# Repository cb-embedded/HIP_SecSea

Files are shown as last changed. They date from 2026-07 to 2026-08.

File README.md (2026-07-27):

# HIP_SecSea
Hack In Provence badge for SecSea

## Changes from V1.1 (@chris_cannes)

This version is based on the V1.1 design by @chris_cannes. The following changes were made:

**Antenna area**
- Antenna placement and copper zones reworked to comply with CC1101 datasheet requirements.
- Replaced four independent copper cutout polygons with a proper keepout zone (larger, as required by the doc).

**Layer stackup**
- Added a dedicated Ground plane (inner layer).
- Added a dedicated 3.3V Power plane (inner layer).
- Main routing moved to Top and Bottom layers.

**Power distribution**
- The 3.3V distribution tree replaced by a solid 3.3V power plane.

**GND stitching**
- Stitching vias replaced by GND vias placed as close as possible to GND pads, connecting directly into the ground plane. This ensures a controlled, low-impedance GND return path.

## TODO (before production)

- [X] Rebuild copper planes and stitching vias: add back a proper grid of stitching vias (perimeter, around RF keepout zone, under CC1101) in addition to the pad-level GND vias.
- [X] **Replace C21 and C26 — 220pF X7R on RF path**: TI reference design specifies NP0/C0G for these positions. Replace with Murata [`GRM1555C1H221JA01D`](https://www.lcsc.com/product-detail/C71693.html) (C0G, 220pF, 50V, 0402, LCSC C71693). Current part [`0402B221K500NT`](https://www.lcsc.com/product-detail/C1530.html) (FH, LCSC C1530, X7R) deviates from reference design; do not second-guess NP0 in an RF path.
- [X] **Verify crystal load capacitors C17, C18 (27pF)**: X2 specifies 15pF load. CC1101 datasheet gives Cparasitic ≈ 2.5pF typical. Effective load = 27/2 + 2.5 = 16pF — 1pF above target, acceptable. Current 27pF value is correct; no change needed unless crystal frequency trim is required.

- [ ] Use tented vias;
- [X] On ne le fait plus (trop long) ~~TODO: Changer pour antenne 868MHz (Meilleure efficacité vs petite taille de PCB), (si simple à changer).~~
- [ ] Prod entre 5 et 10.

## Production Preview JLCPCB

See [JLCPCB Pictures in this folder](KiCad_src_V1_2/production_preview)

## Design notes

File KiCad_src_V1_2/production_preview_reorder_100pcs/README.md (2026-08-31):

# Production JLCPCB 100pcs

## Coût

Coût d'environs **14€ par Badge pour 100pcs** *(contre 65€ lors de la phase de prototypage)*

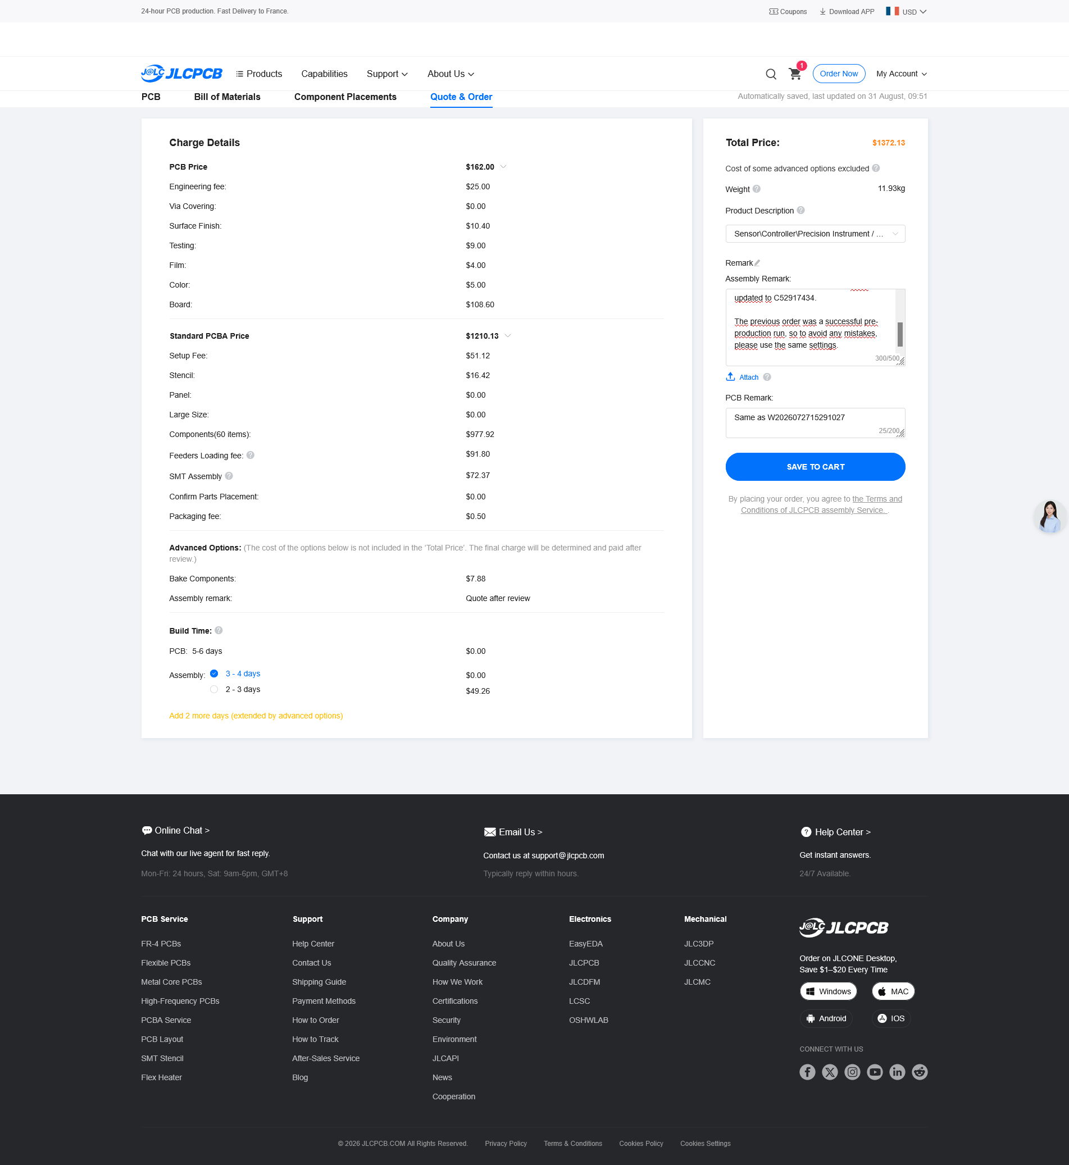
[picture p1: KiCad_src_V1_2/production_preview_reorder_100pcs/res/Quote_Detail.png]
Quote


## Remarques

- **Mise à jour mineure de la BOM:**
  - La référence des LEDs WS2812B à été mise à jour. En effet, la précédente révision WS2812B-2020 (C965555) est en rupture de stock. Elle a été remplacée dans la BOM par la V6: WS2812B-2020-V6 (C52917434)

- **Demande explicite à JLCPCB de rejouer les mêmes paramètres que la pré-production**:
  - Comme il a fallu mettre à jour la BOM, cela a recréé une commande (pas le même circuit qu'un vrai reorder),
  - Par contre, il s'agit du même gerber et de la même base de BOM que précédemment (pas de réupload des fichiers, ni du pick'n place).
  - Le transistor Q2 n'avait pas la bonne orientation dans la preview, j'ai corrigé manuellement via la GUI de placement JLCPCB.

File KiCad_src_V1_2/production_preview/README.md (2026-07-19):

# Commande JLCPCB — Badge HIP SecSea V1.2

Estimatif JLCPCB — 5 exemplaires, assemblage double face. À valider (quantité, coût).

## Page 1 — Paramètres PCB & Assemblage

- **PCB** : 4 couches, 1.6 mm, HASL Lead Free, couleur noire, 5 pcs
- **Surface finish** : LeadFree HASL
- **Assembly** : Both Sides (Top + Bottom), 5 pcs
- **Advanced options** : Bake Components activé (requis pour les WS2812B, sensibles à l'humidité)

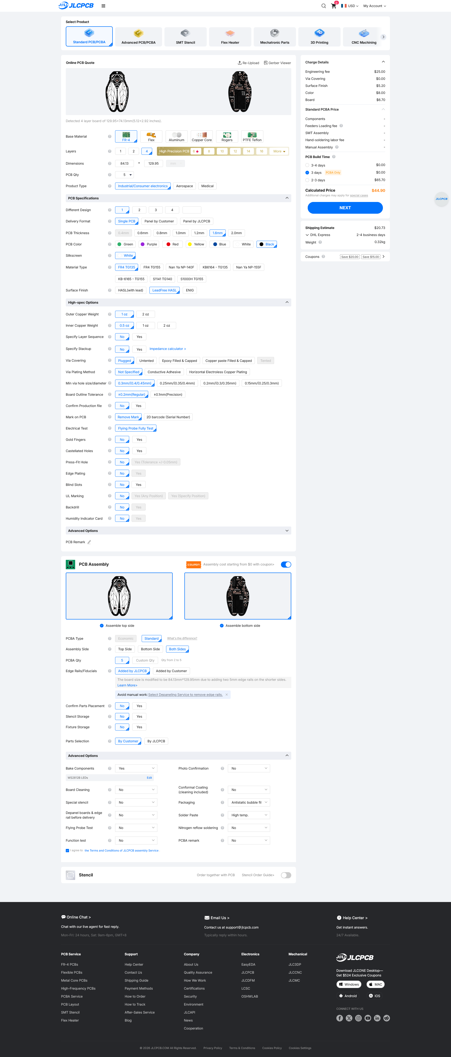
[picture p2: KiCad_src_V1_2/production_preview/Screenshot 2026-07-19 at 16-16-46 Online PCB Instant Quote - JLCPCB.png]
Paramètres de production JLCPCB


## Page 2 — BOM & Placement

### BOM exhaustive

Prix en dollars. Fichier complet :
[bom-JLCPCB Assembly Order.xls](bom-JLCPCB%20Assembly%20Order.xls)

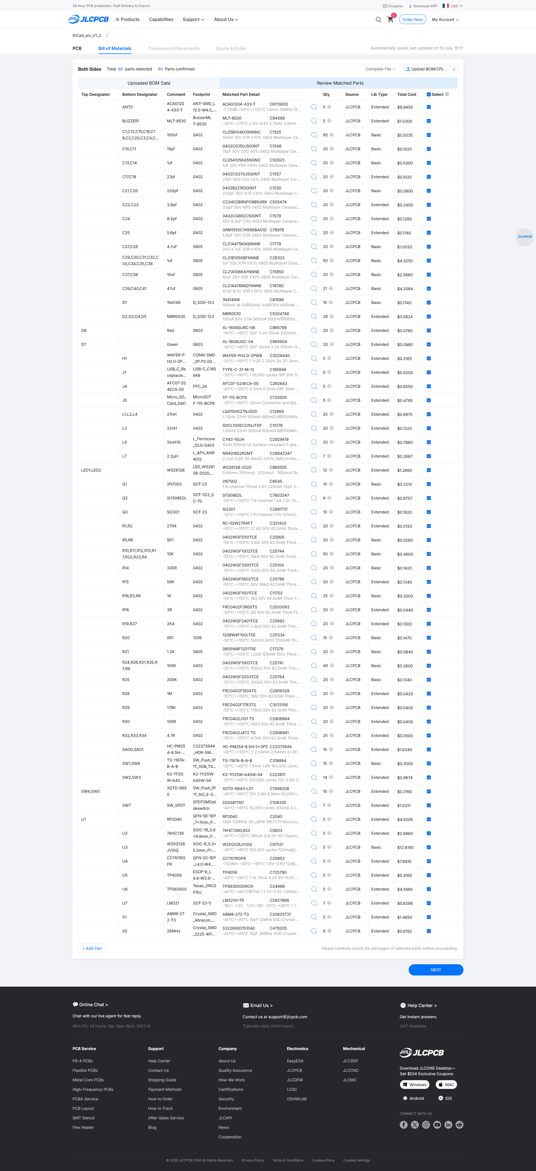
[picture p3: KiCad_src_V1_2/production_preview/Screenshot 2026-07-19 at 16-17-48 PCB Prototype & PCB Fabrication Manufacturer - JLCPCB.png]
BOM exhaustive JLCPCB


#### Top 10 des composants par coût (par PCB, sur 5 pièces)

| # | Désignateur | Composant | $/PCB |
| --- | --- | --- | ----: |
| 1 | U3 | W25Q128JVSIQ — Flash QSPI 128Mbit | $2.52 |
| 2 | ANT0 | ACAG1204-433-T — Antenne céramique 433MHz | $1.99 |
| 3 | U4 | CC1101RGPR — RF transceiver sub-GHz | $1.54 |
| 4 | U1 | RP2040 — MCU | $0.98 |
| 5 | U6 | TPS63000DRCR — Buck-boost DC-DC | $0.91 |
| 6 | C29–C36 | 1µF 0805 × 8 | $0.86 |
| 7 | C39–C41 | 47µF 0805 × 3 | $0.84 |
| 8 | U2 | 74HC139D — Démultiplexeur 2:4 | $0.53 |
| 9 | C37–C38 | 10µF 0805 × 2 | $0.51 |
| 10  | SAO0, SAO1  | HC-PM254-8.5H-2×3PS — Connecteurs femelle SAO | $0.33 |

Total composants (5 pièces) : **$74.41** → **$14.88/PCB**

### Preview placement — Face avant (Top)

Vue générale de la face avant : RP2040, LEDs WS2812B, boutons SW4/SW5, LEDs de statut D6/D7.

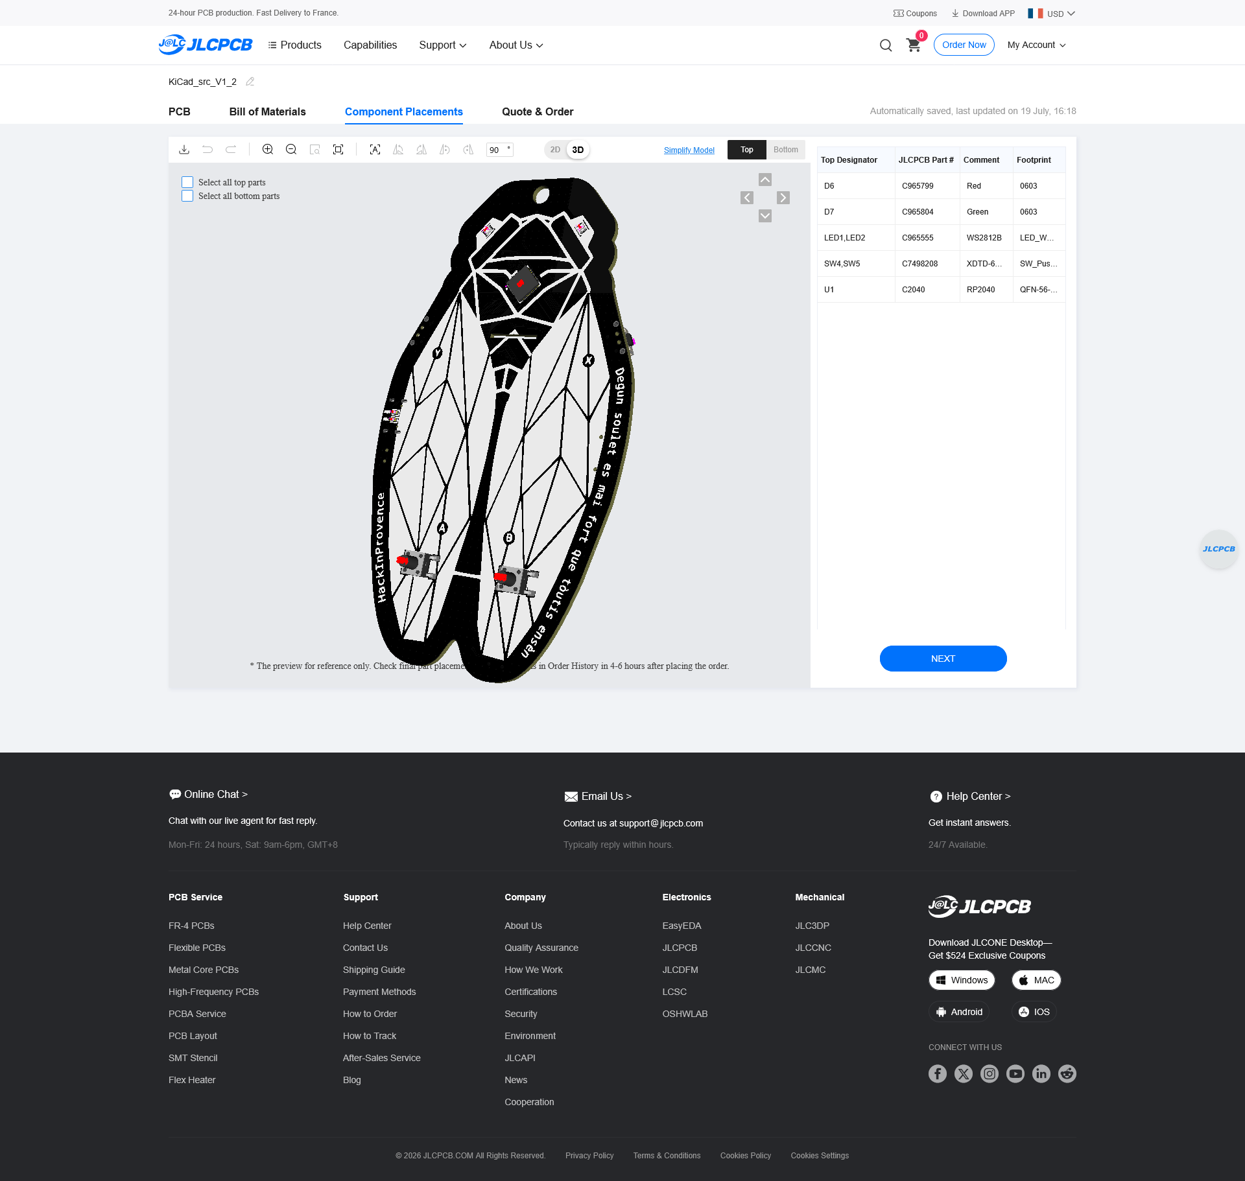
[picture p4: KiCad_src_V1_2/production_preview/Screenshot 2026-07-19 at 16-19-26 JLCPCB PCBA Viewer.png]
Preview placement front — vue générale


### Preview placement — Face arrière (Bottom) — vue générale

Vue générale de la face arrière : RP2040 (U1), CC1101 RF 433MHz (U4), antenne céramique ANT0, flash QSPI W25Q128 (U3), demux 74HC139 (U2), buck-boost TPS63000 (U6), chargeur TP4056 (U5), connecteurs USB-C / MicroSD / SAO, passifs.

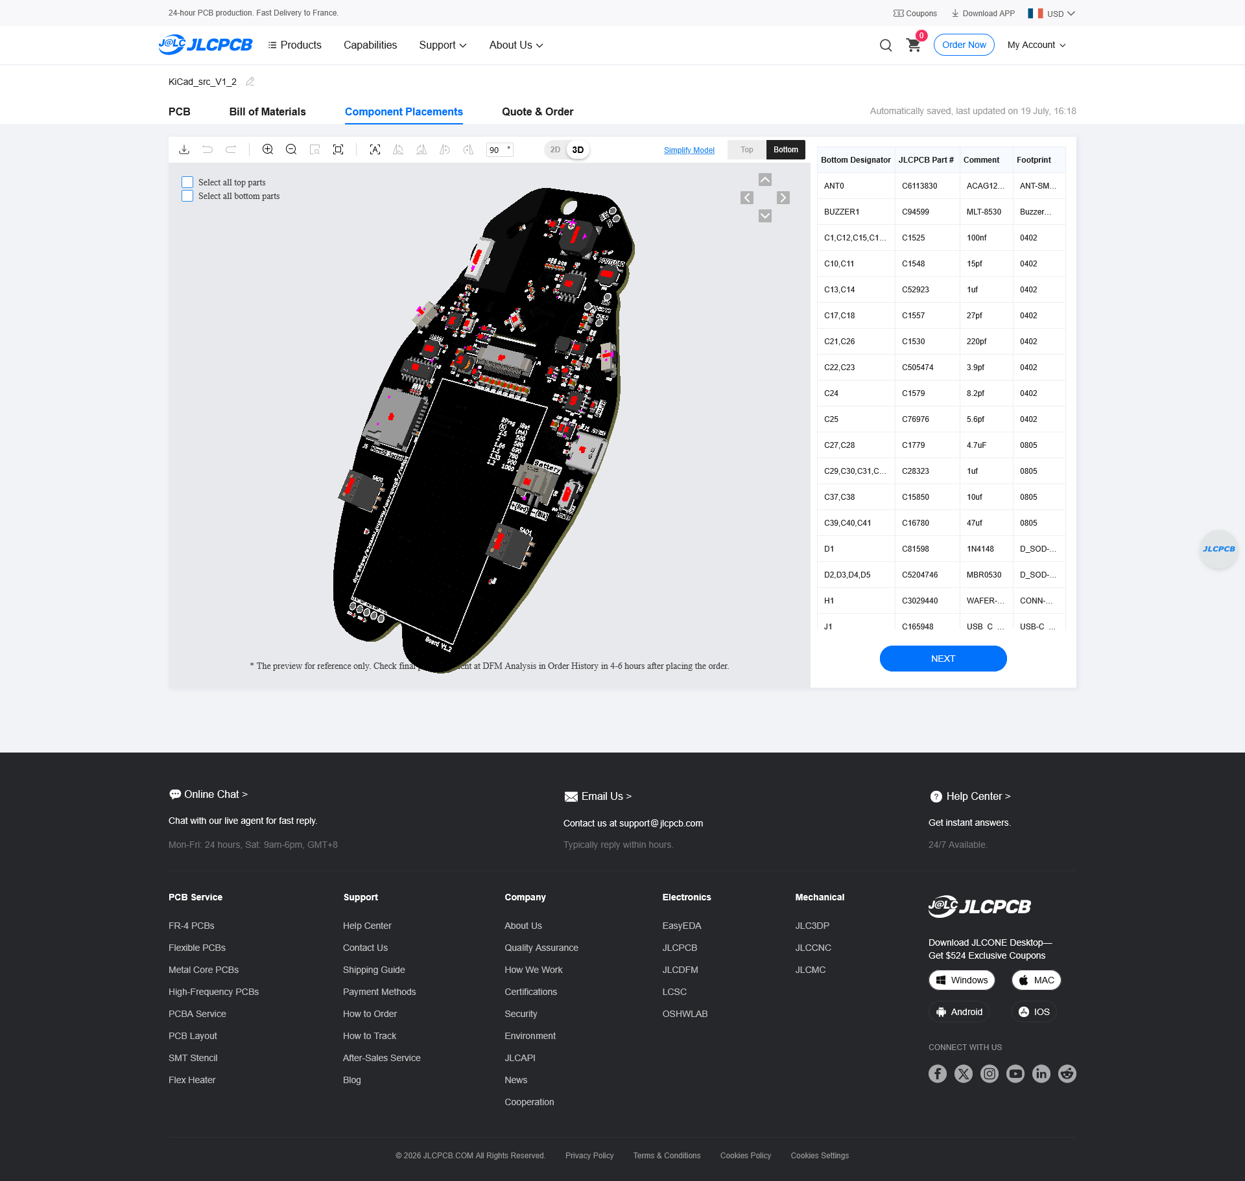
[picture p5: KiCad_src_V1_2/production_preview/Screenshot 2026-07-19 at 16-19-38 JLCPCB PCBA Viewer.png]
Preview placement back — vue générale


### Preview placement — Face arrière zoomée — bas de carte

Zoom sur la zone basse de la carte.

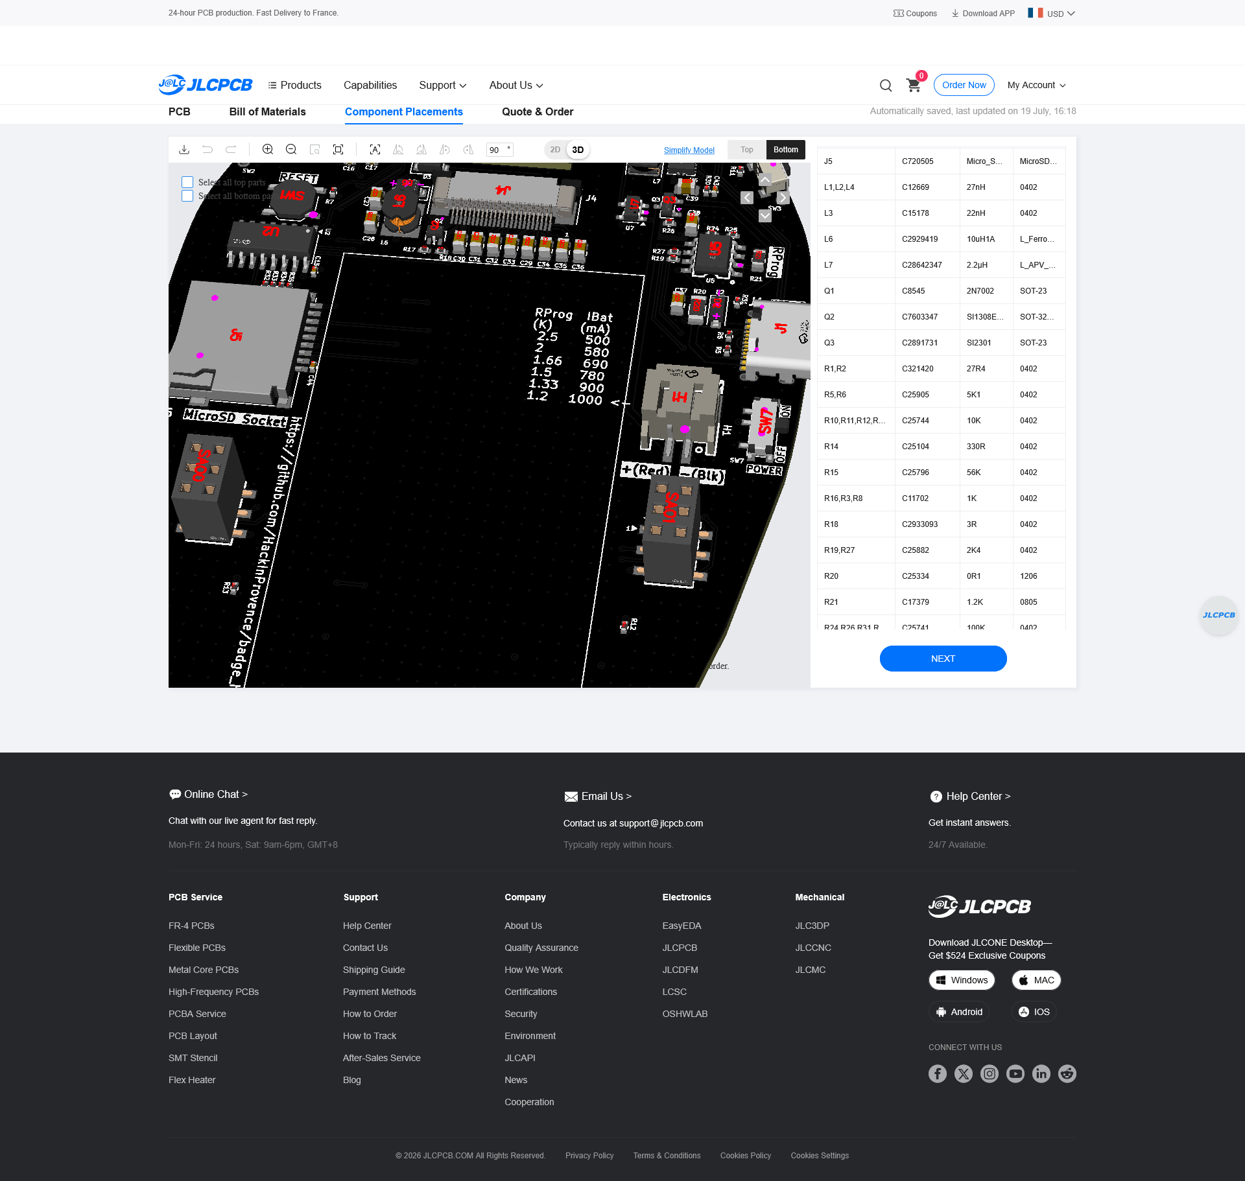
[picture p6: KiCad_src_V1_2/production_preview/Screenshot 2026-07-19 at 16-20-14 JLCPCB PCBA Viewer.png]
Preview placement back — zoom bas


### Preview placement — Face arrière zoomée — haut de carte

Zoom sur la zone haute de la carte.

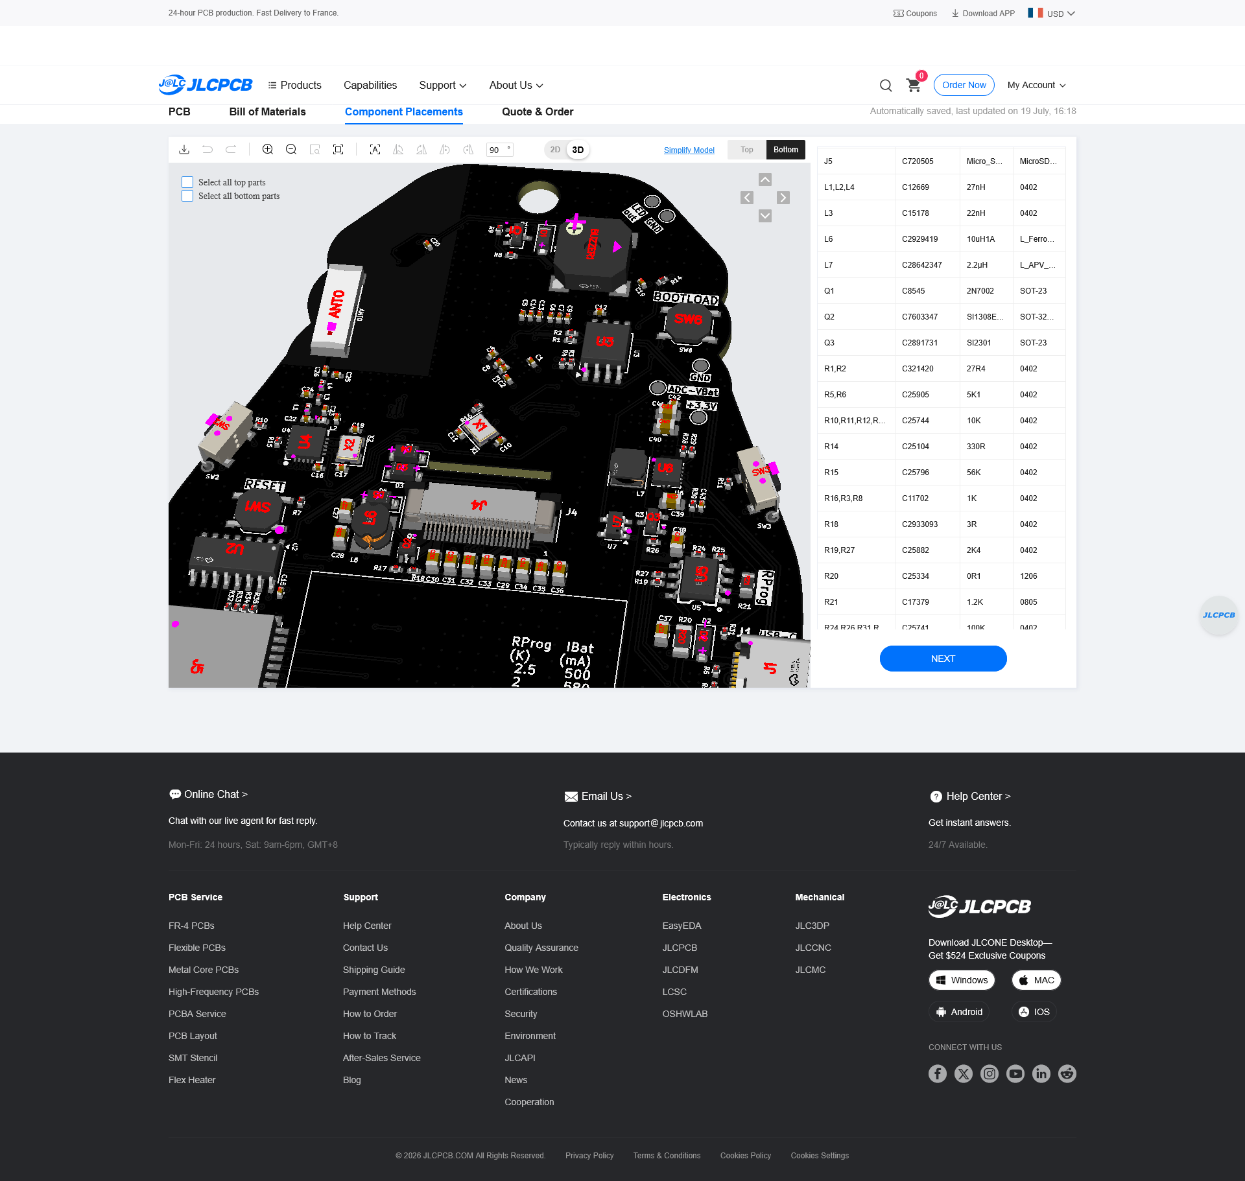
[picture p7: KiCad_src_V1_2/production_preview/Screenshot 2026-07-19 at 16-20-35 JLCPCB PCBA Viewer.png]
Preview placement back — zoom haut


## Récapitulatif des prix (hors shipping)

- **PCB Price** : $44.90
  - Engineering fee : $25.00
  - Via Covering : $0.00
  - Surface Finish : $5.20
  - Color : $8.00
  - Board : $6.70
- **Standard PCBA Price** : $239.33
  - Setup Fee : $51.12
  - Stencil : $16.42
  - Panel : $0.00
  - Large Size : $0.00
  - Components (60 items) : $74.41
  - Feeders Loading fee : $91.80
  - SMT Assembly : $5.08
  - Packaging fee : $0.50
- **Advanced Options — Bake Components** : $7.88
- **Sous-total** : $284.23

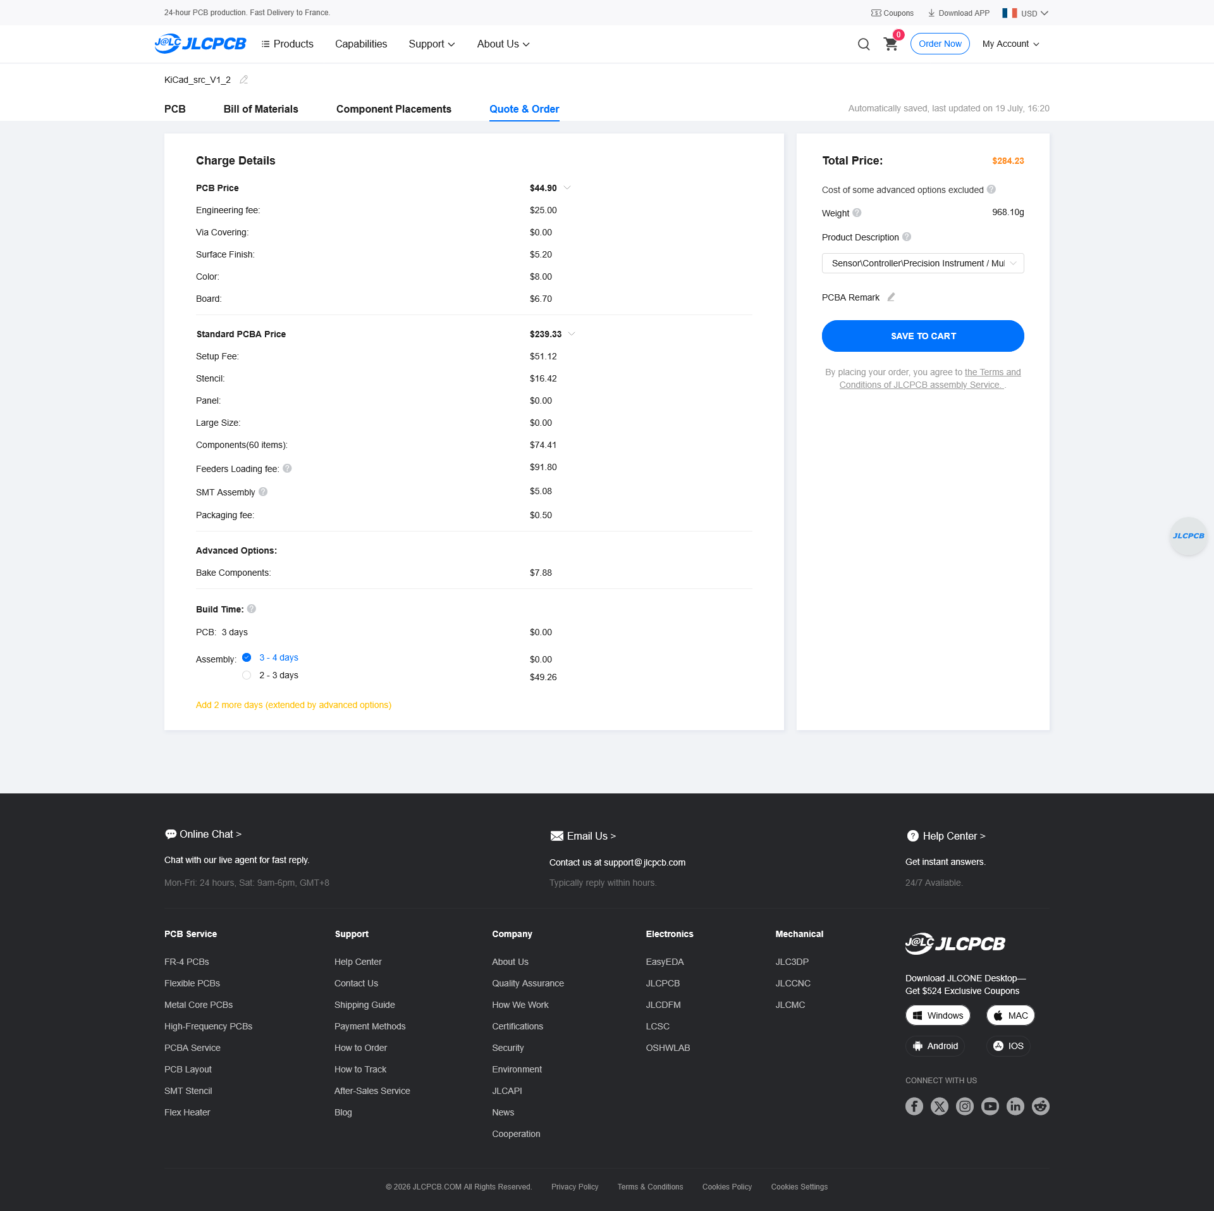
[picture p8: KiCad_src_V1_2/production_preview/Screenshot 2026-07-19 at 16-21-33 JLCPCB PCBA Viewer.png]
Récapitulatif des prix JLCPCB


## Total final avec shipping et douanes

| Poste | Montant |
| --- | --- |
| Merchandise Total | $284.23 |
| Shipping Estimate (DHL Express DDP, 2-4 business days) | $32.51 |
| Customs duties & taxes | $63.35 |
| Payment fee (PayPal) | $1.90 |
| **Grand Total** | **$381.99** |

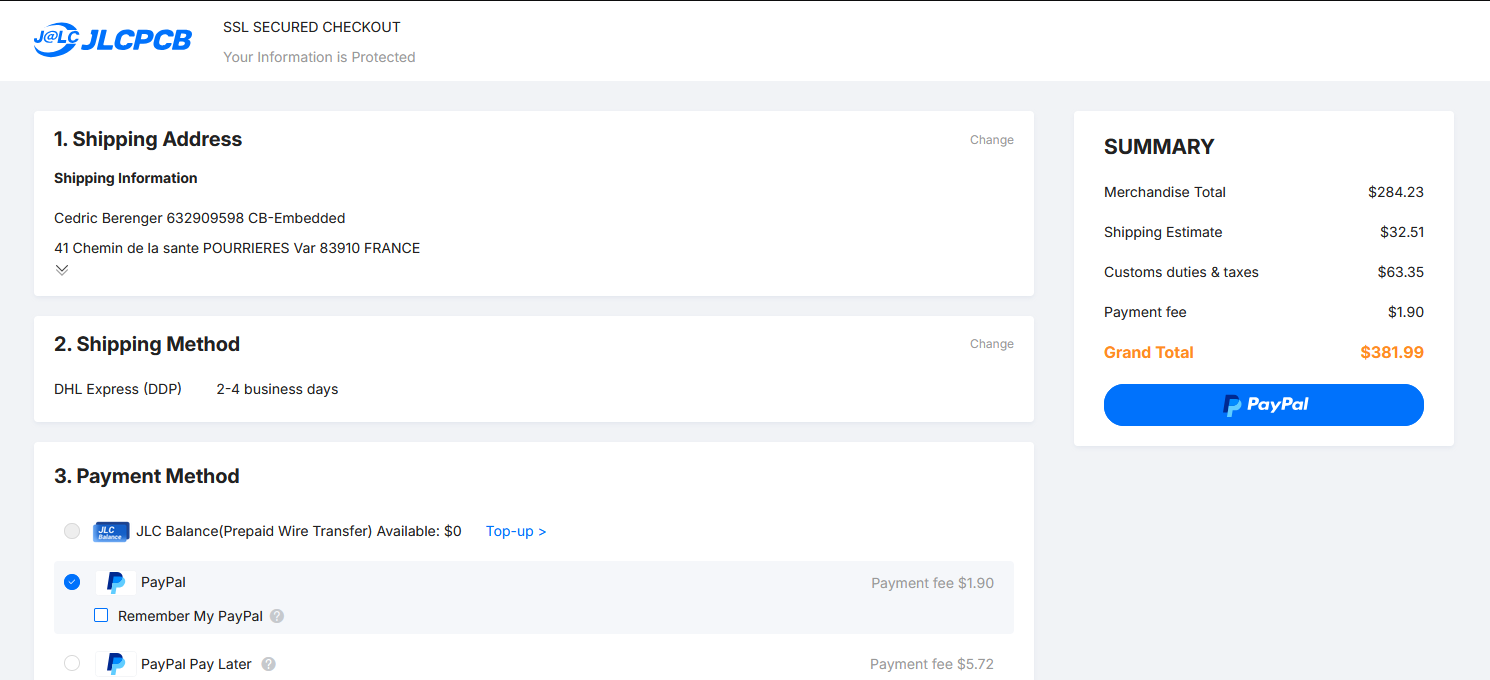
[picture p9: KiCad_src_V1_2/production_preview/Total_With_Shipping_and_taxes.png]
Total commande avec shipping et taxes


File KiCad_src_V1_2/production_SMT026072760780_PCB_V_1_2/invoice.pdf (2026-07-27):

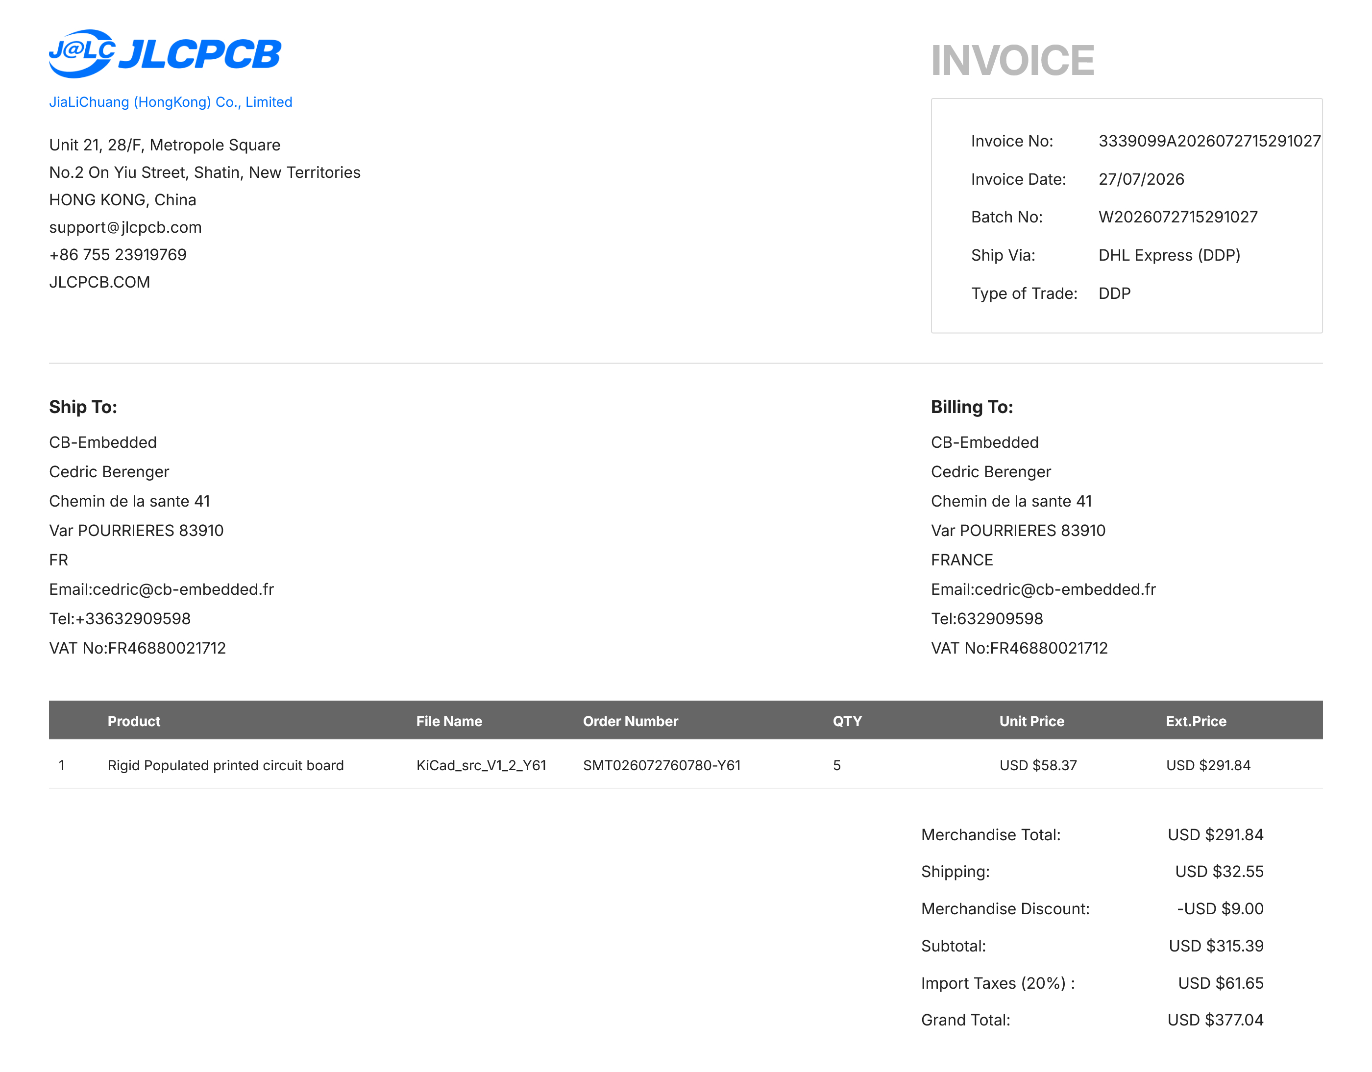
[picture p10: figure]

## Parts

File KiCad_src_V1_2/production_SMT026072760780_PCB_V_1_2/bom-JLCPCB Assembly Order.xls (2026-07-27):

JLCPCB BOM Tool - BOM Matching
BOM name：bom-JLCPCB Assembly Order.xlsx |  |  | Download Time：2026-07-27 15:27:50 |  |  |  | * Our matching results are updated in real-time, but stock and prices may change. If it's been over 24 hours, please re-match before placing your order.
PCB Assembled Qty：5 |  |  | Est. Total Price：74.1405
Your BOM |  |  |  |  | Matched Parts |  |  |  |  |  |  | Order Information
Top Designator | Bottom Designator | Comment | Footprint | JLCPCB Part # | Matches | Part # | Manufacturer | Footprint | Description | Category | Warning | JLCPCB Part # | Product link | Lib Type | Qty | Source | Total Price ($)
 | ANT0 | ACAG1204-433-T | ANT-SMD_L12.0-W4.0_ACAG1204-915-T |  | Select by System | ACAG1204-433-T | Abracon LLC | SMD,12x4mm | -1.72dBi -55℃~+125℃ 1.6mm 10MHz 12mm 2 433MHz 4mm 50Ω Ceramic Antenna SMD,12x4mm Antennas ROHS | Antennas |  | C6113830 | https://jlcpcb.com/partdetail/AbraconLLC-ACAG1204_433T/C6113830 | Extended | 5 | 5 JLCPCB | 9.9555
 | BUZZER1 | MLT-8530 | BuzzerMLT-8530 |  | Select by System | MLT-8530 | Jiangsu Huaneng Elec | SMD,8.5x8.5mm | -20℃~+70℃ 2.5V~4.5V 2.7kHz 3.3mm 3.6V 8.5mm 8.5mm 80dB 95mA Electromagnetic Passive (Externally Driven) SMD SMD,8.5x8.5mm Buzzers ROHS | Buzzers |  | C94599 | https://jlcpcb.com/partdetail/Jiangsu_HuanengElec-MLT8530/C94599 | Extended | 5 | 5 JLCPCB | 1.0315
 | C1,C12,C15,C16,C19,C2,C20,C3,C4,C42,C43,C44,C5,C6,C7,C8,C9 | 100nf | 0402 |  | Select by System | CL05B104KO5NNNC | Samsung Electro-Mechanics | 0402 | 100nF 16V X7R ±10% 0402 Multilayer Ceramic Capacitors MLCC - SMD/SMT ROHS | Multilayer Ceramic Capacitors MLCC - SMD/SMT |  | C1525 | https://jlcpcb.com/partdetail/1877-CL05B104KO5NNNC/C1525 | Basic | 95 | 95 JLCPCB | 0.5035
 | C10,C11 | 15pf | 0402 |  | Select by System | 0402CG150J500NT | FH (Guangdong Fenghua Advanced Tech) | 0402 | 15pF 50V C0G ±5% 0402 Multilayer Ceramic Capacitors MLCC - SMD/SMT ROHS | Multilayer Ceramic Capacitors MLCC - SMD/SMT |  | C1548 | https://jlcpcb.com/partdetail/1900-0402CG150J500NT/C1548 | Basic | 20 | 20 JLCPCB | 0.1
 | C13,C14 | 1uf | 0402 |  | Select by System | CL05A105KA5NQNC | Samsung Electro-Mechanics | 0402 | 1uF 25V X5R ±10% 0402 Multilayer Ceramic Capacitors MLCC - SMD/SMT ROHS | Multilayer Ceramic Capacitors MLCC - SMD/SMT |  | C52923 | https://jlcpcb.com/partdetail/53938-CL05A105KA5NQNC/C52923 | Basic | 20 | 20 JLCPCB | 0.53
 | C17,C18 | 27pf | 0402 |  | Select by System | 0402CG270J500NT | FH (Guangdong Fenghua Advanced Tech) | 0402 | 27pF 50V C0G ±5% 0402 Multilayer Ceramic Capacitors MLCC - SMD/SMT ROHS | Multilayer Ceramic Capacitors MLCC - SMD/SMT |  | C1557 | https://jlcpcb.com/partdetail/1909-0402CG270J500NT/C1557 | Extended | 20 | 20 JLCPCB | 0.102
 | C21,C26 | 220pf | 0402 |  | Select by System | 0402B221K500NT | FH (Guangdong Fenghua Advanced Tech) | 0402 | 220pF 50V X7R ±10% 0402 Multilayer Ceramic Capacitors MLCC - SMD/SMT ROHS | Multilayer Ceramic Capacitors MLCC - SMD/SMT |  | C1530 | https://jlcpcb.com/partdetail/1882-0402B221K500NT/C1530 | Basic | 20 | 20 JLCPCB | 0.08
 | C22,C23 | 3.9pf | 0402 |  | Select by System | CC0402BRNPO9BN3R9 | YAGEO | 0402 | 3.9pF 50V NP0 0402 Multilayer Ceramic Capacitors MLCC - SMD/SMT ROHS | Multilayer Ceramic Capacitors MLCC - SMD/SMT |  | C505474 | https://jlcpcb.com/partdetail/YAGEO-CC0402BRNPO9BN3R9/C505474 | Extended | 20 | 20 JLCPCB | 0.26
 | C24 | 8.2pf | 0402 |  | Select by System | 0402CG8R2C500NT | FH (Guangdong Fenghua Advanced Tech) | 0402 | 50V 8.2pF C0G 0402 Multilayer Ceramic Capacitors MLCC - SMD/SMT ROHS | Multilayer Ceramic Capacitors MLCC - SMD/SMT |  | C1579 | https://jlcpcb.com/partdetail/1931-0402CG8R2C500NT/C1579 | Extended | 20 | 20 JLCPCB | 0.13
 | C25 | 5.6pf | 0402 |  | Select by System | GRM1555C1H5R6BA01D | Murata Electronics | 0402 | 5.6pF 50V C0G 0402 Multilayer Ceramic Capacitors MLCC - SMD/SMT ROHS | Multilayer Ceramic Capacitors MLCC - SMD/SMT |  | C76976 | https://jlcpcb.com/partdetail/MurataElectronics-GRM1555C1H5R6BA01D/C76976 | Extended | 20 | 20 JLCPCB | 0.114
 | C27,C28 | 4.7uF | 0805 |  | Select by System | CL21A475KAQNNNE | Samsung Electro-Mechanics | 0805 | 25V 4.7uF X5R ±10% 0805 Multilayer Ceramic Capacitors MLCC - SMD/SMT ROHS | Multilayer Ceramic Capacitors MLCC - SMD/SMT |  | C1779 | https://jlcpcb.com/partdetail/2131-CL21A475KAQNNNE/C1779 | Basic | 20 | 20 JLCPCB | 1.004
 | C29,C30,C31,C32,C33,C34,C35,C36 | 1uf | 0805 |  | Select by System | CL21B105KBFNNNE | Samsung Electro-Mechanics | 0805 | 1uF 50V X7R ±10% 0805 Multilayer Ceramic Capacitors MLCC - SMD/SMT ROHS | Multilayer Ceramic Capacitors MLCC - SMD/SMT |  | C28323 | https://jlcpcb.com/partdetail/29074-CL21B105KBFNNNE/C28323 | Basic | 50 | 50 JLCPCB | 4.325
 | C37,C38 | 10uf | 0805 |  | Select by System | CL21A106KAYNNNE | Samsung Electro-Mechanics | 0805 | 10uF 25V X5R ±10% 0805 Multilayer Ceramic Capacitors MLCC - SMD/SMT ROHS | Multilayer Ceramic Capacitors MLCC - SMD/SMT |  | C15850 | https://jlcpcb.com/partdetail/16532-CL21A106KAYNNNE/C15850 | Basic | 20 | 20 JLCPCB | 2.38
 | C39,C40,C41 | 47uf | 0805 |  | Select by System | CL21A476MQYNNNE | Samsung Electro-Mechanics | 0805 | 47uF 6.3V X5R ±20% 0805 Multilayer Ceramic Capacitors MLCC - SMD/SMT ROHS | Multilayer Ceramic Capacitors MLCC - SMD/SMT |  | C16780 | https://jlcpcb.com/partdetail/17464-CL21A476MQYNNNE/C16780 | Basic | 21 | 21 JLCPCB | 4.2126
 | D1 | 1N4148 | D_SOD-123 |  | Select by System | 1N4148W | ST(Semtech) | SOD-123 | 150mA 1A 1V@50mA 1uA@75V 400mW 4ns 75V Independent SOD-123 Switching Diodes ROHS | Switching Diodes |  | C81598 | https://jlcpcb.com/partdetail/ST_Semtech-1N4148W/C81598 | Basic | 15 | 15 JLCPCB | 0.1755
 | D2,D3,D4,D5 | MBR0530 | D_SOD-123 |  | Select by System | MBR0530 | TWGMC | SOD-123 | 130uA 30V 5.5A 500mA 500mV@500mA Independent SOD-123 Schottky Diodes ROHS | Schottky Diodes |  | C5204746 | https://jlcpcb.com/partdetail/TWGMC-MBR0530/C5204746 | Extended | 28 | 28 JLCPCB | 0.5824
D6 |  | Red | 0603 |  | Select by System | XL-1608SURC-06 | XINGLIGHT | 0603 | -40℃~+85℃ 120° 2.3V 20mA 225mcd 50mW 620nm~630nm 625nm Discrete Diode Red Top-mount Water Clear 0603 LED Indication - Discrete ROHS | LED Indication - Discrete |  | C965799 | https://jlcpcb.com/partdetail/XINGLIGHT-XL_1608SURC06/C965799 | Extended | 20 | 20 JLCPCB | 0.076
D7 |  | Green | 0603 |  | Select by System | XL-1608UGC-04 | XINGLIGHT | 0603 | -40℃~+85℃ 120° 20mA 3.3V 515nm~535nm 525nm 70mW 810mcd Discrete Diode Emerald Green Top-mount Water Clear 0603 LED Indication - Discrete ROHS | LED Indication - Discrete |  | C965804 | https://jlcpcb.com/partdetail/XINGLIGHT-XL_1608UGC04/C965804 | Extended | 20 | 20 JLCPCB | 0.098
 | H1 | WAFER-PH2.0-2PWB | CONN-SMD_2P-P2.00_XUNPU_WAFER-PH2.0-2PWB |  | Select by System | WAFER-PH2.0-2PWB | XUNPU | SMD,P=2mm,卧贴 | -25℃~+85℃ 1 1x2P 2 250V 2A 2P 2mm 5.6mm 7.59mm 8mm Auxiliary Solder Pin Beige Brass LCP PH Surface Mount, Right Angle Tin SMD,P=2mm,卧贴 Wire To Board Connector ROHS | Wire To Board Connector |  | C3029440 | https://jlcpcb.com/partdetail/XUNPU-WAFER_PH2_02PWB/C3029440 | Extended | 5 | 5 JLCPCB | 0.317
 | J1 | USB_C_Receptacle_USB2.0_14P | USB-C_C165948 |  | Select by System | TYPE-C-31-M-12 | Korean Hroparts Elec | SMD | -30℃~+80℃ 1 10,000 cycles 16P 20V 5A 7.35mm Female Surface Mount, Right Angle Type-C SMD USB Connectors ROHS | USB Connectors |  | C165948 | https://jlcpcb.com/partdetail/Korean_HropartsElec-TYPE_C_31_M12/C165948 | Extended | 5 | 5 JLCPCB | 0.921
 | J4 | AFC07-S24ECA-00 | FPC_24 |  | Select by System | AFC07-S24ECA-00 | JUSHUO | SMD,P=0.5mm,卧贴 | -45℃~+85℃ 0.3mm 0.5mm 24P 2mm 500mA 50V Copper alloy Slide Lock Surface Mount, Right Angle Tin Top Contact SMD,P=0.5mm,卧贴 FFC, FPC (Flat Flexible) Connector Assemblies ROHS | FFC, FPC (Flat Flexible) Connector Assemblies |  | C262643 | https://jlcpcb.com/partdetail/JUSHUO-AFC07_S24ECA00/C262643 | Extended | 5 | 5 JLCPCB | 0.6555
 | J5 | Micro_SD_Card_Det1 | MicroSDTF-115-BCP9 |  | Select by System | TF-115-BCP9 | XUNPU | SMD | -25℃~+85℃ 1.8mm Connector and Ejector MicroSD Card (TF Card) Push-Push SMD SD Card / Memory Card Connector ROHS | SD Card / Memory Card Connector |  | C720505 | https://jlcpcb.com/partdetail/XUNPU-TF_115BCP9/C720505 | Extended | 5 | 5 JLCPCB | 0.48
 | L1,L2,L4 | 27nH | 0402 |  | Select by System | LQG15HS27NJ02D | Murata Electronics | 0402 | 1.7GHz 27nH 350mA 460mΩ 8@100MHz ±5% 0402 Inductors (SMD) ROHS | Inductors (SMD) |  | C12669 | https://jlcpcb.com/partdetail/MurataElectronics-LQG15HS27NJ02D/C12669 | Extended | 25 | 25 JLCPCB | 0.47
 | L3 | 22nH | 0402 |  | Select by System | SDCL1005C22NJTDF | Sunlord | 0402 | 1.9GHz 22nH 300mA 600mΩ 8@100MHz ±5% 0402 Inductors (SMD) ROHS | Inductors (SMD) |  | C15178 | https://jlcpcb.com/partdetail/Sunlord-SDCL1005C22NJTDF/C15178 | Extended | 20 | 20 JLCPCB | 0.132
 | L6 | 10uH1A | L_Ferrocore_DLG-0403 |  | Select by System | CY43-10UH | SHOU HAN | SMD,4.5x4mm | 10uH 150mΩ 1A Surface-mounted T-shaped inductor ±20% SMD,4.5x4mm Inductors (SMD) ROHS | Inductors (SMD) |  | C2929419 | https://jlcpcb.com/partdetail/SHOUHAN-CY4310UH/C2929419 | Extended | 20 | 20 JLCPCB | 0.798
 | L7 | 2.2µH | L_APV_ANR4012 |  | Select by System | NR4018S2R2MT | Magnetsyc | SMD,4x4mm | 2.2uH 3.2A 3A 48mΩ ±20% SMD,4x4mm Power Inductors ROHS | Power Inductors |  | C28642347 | https://jlcpcb.com/partdetail/Magnetsyc-NR4018S2R2MT/C28642347 | Extended | 7 | 7 JLCPCB | 0.2667
LED1,LED2 |  | WS2812B | LED_WS2812B-2020_PLCC4_2.0x2.0mm |  | Select by System | WS2812B-2020 | Worldsemi | SMD,2.2x2mm | 0.84mm 200mcd、520mcd、160mcd 2kHz 5V 800Kbit/s Built-in power-on reset circuit、Built-in power-on reset circuit、Integrated intelligent reverse connection protection function R:622.5nm、G:515.6nm、B:470.4nm Top-mount SMD,2.2x2mm RGB LEDs(Built-in IC) ROHS | RGB LEDs(Built-In IC) |  | C965555 | https://jlcpcb.com/partdetail/Worldsemi-WS2812B2020/C965555 | Extended | 12 | 12 JLCPCB | 1.2672
 | Q1 | 2N7002 | SOT-23 |  | Select by System | 2N7002 | Jiangsu Changjing Electronics Technology Co., Ltd. | SOT-23 | 1 N-channel 115mA 2.5V 225mW 25pF 50pF 5pF 5Ω@10V 60V N-Channel ±20V SOT-23 MOSFETs ROHS | MOSFETs |  | C8545 | https://jlcpcb.com/partdetail/9040-2N7002/C8545 | Basic | 10 | 10 JLCPCB | 0.176
 | Q2 | SI1308EDL | SOT-323_SC-70 |  | Select by System | SI1308EDL | TECH PUBLIC | SOT-323 | -55℃~+150℃ 1 N-channel 1.4A 1.5V 14.8pF 146pF 150mΩ@4.5V 18.3pF 2.6nC@4.5V 30V 360mW SOT-323 MOSFETs ROHS | MOSFETs |  | C7603347 | https://jlcpcb.com/partdetail/TECHPUBLIC-SI1308EDL/C7603347 | Extended | 9 | 9 JLCPCB | 0.8766
 | Q3 | SI2301 | SOT-23 |  | Select by System | SI2301 | YONGYUTAI | SOT-23 | -55℃~+150℃ 1 P-Channel 1.5V 120mΩ@4.5V 2.2A 200pF 20V 700mW 80pF P-Channel SOT-23 MOSFETs ROHS | MOSFETs |  | C2891731 | https://jlcpcb.com/partdetail/YONGYUTAI-SI2301/C2891731 | Extended | 10 | 10 JLCPCB | 0.192
 | R1,R2 | 27R4 | 0402 |  | Select by System | RC-02W27R4FT | FH (Guangdong Fenghua Advanced Tech) | 0402 | -55℃~+155℃ 27.4Ω 50V 62.5mW Thick Film Resistor ±1% ±200ppm/℃ 0402 Chip Resistor - Surface Mount ROHS | Chip Resistor - Surface Mount |  | C321420 | https://jlcpcb.com/partdetail/302325-RC02W27R4FT/C321420 | Extended | 20 | 20 JLCPCB | 0.012
 | R5,R6 | 5K1 | 0402 |  | Select by System | 0402WGF5101TCE | UNI-ROYAL(Uniroyal Elec) | 0402 | -55℃~+155℃ 5.1kΩ 50V 62.5mW Thick Film Resistor ±1% ±100ppm/℃ 0402 Chip Resistor - Surface Mount ROHS | Chip Resistor - Surface Mount |  | C25905 | https://jlcpcb.com/partdetail/26648-0402WGF5101TCE/C25905 | Basic | 20 | 20 JLCPCB | 0.134
 | R10,R11,R12,R13,R17,R22,R23,R4 | 10K | 0402 |  | Select by Customer | RC0402FR-0710KL | YAGEO | 0402 | -55℃~+155℃ 10kΩ 50V 62.5mW Thick Film Resistor ±1% ±100ppm/℃ 0402 Chip Resistor - Surface Mount ROHS | Chip Resistor - Surface Mount |  | C60490 | https://jlcpcb.com/partdetail/YAGEO-RC0402FR0710KL/C60490 | Extended | 50 | 50 JLCPCB | 0.29
 | R14 | 330R | 0402 |  | Select by System | 0402WGF3300TCE | UNI-ROYAL(Uniroyal Elec) | 0402 | -55℃~+155℃ 330Ω 50V 62.5mW Thick Film Resistor ±1% ±100ppm/℃ 0402 Chip Resistor - Surface Mount ROHS | Chip Resistor - Surface Mount |  | C25104 | https://jlcpcb.com/partdetail/25847-0402WGF3300TCE/C25104 | Basic | 20 | 20 JLCPCB | 0.034
 | R15 | 56K | 0402 |  | Select by System | 0402WGF5602TCE | UNI-ROYAL(Uniroyal Elec) | 0402 | -55℃~+155℃ 50V 56kΩ 62.5mW Thick Film Resistor ±1% ±100ppm/℃ 0402 Chip Resistor - Surface Mount ROHS | Chip Resistor - Surface Mount |  | C25796 | https://jlcpcb.com/partdetail/26539-0402WGF5602TCE/C25796 | Extended | 20 | 20 JLCPCB | 0.152
 | R16,R3,R8 | 1K | 0402 |  | Select by System | 0402WGF1001TCE | UNI-ROYAL(Uniroyal Elec) | 0402 | -55℃~+155℃ 1kΩ 50V 62.5mW Thick Film Resistor ±1% ±100ppm/℃ 0402 Chip Resistor - Surface Mount ROHS | Chip Resistor - Surface Mount |  | C11702 | https://jlcpcb.com/partdetail/12256-0402WGF1001TCE/C11702 | Basic | 25 | 25 JLCPCB | 0.2
 | R18 | 3R | 0402 |  | Select by System | FRC0402F3R00TS | FOJAN | 0402 | -55℃~+155℃ 3Ω 50V 62.5mW Thick Film Resistor ±1% ±200ppm/℃ 0402 Chip Resistor - Surface Mount ROHS | Chip Resistor - Surface Mount |  | C2933093 | https://jlcpcb.com/partdetail/FOJAN-FRC0402F3R00TS/C2933093 | Extended | 20 | 20 JLCPCB | 0.044
 | R19,R27 | 2K4 | 0402 |  | Select by System | 0402WGF2401TCE | UNI-ROYAL(Uniroyal Elec) | 0402 | -55℃~+155℃ 2.4kΩ 50V 62.5mW Thick Film Resistor ±1% ±100ppm/℃ 0402 Chip Resistor - Surface Mount ROHS | Chip Resistor - Surface Mount |  | C25882 | https://jlcpcb.com/partdetail/26625-0402WGF2401TCE/C25882 | Extended | 20 | 20 JLCPCB | 0.13
 | R20 | 0R1 | 1206 |  | Select by System | 1206W4F100LT5E | UNI-ROYAL(Uniroyal Elec) | 1206 | -55℃~+155℃ 100mΩ 200V 250mW Thick Film Resistor ±1% ±800ppm/℃ 1206 Chip Resistor - Surface Mount ROHS | Chip Resistor - Surface Mount |  | C25334 | https://jlcpcb.com/partdetail/26077-1206W4F100LT5E/C25334 | Basic | 15 | 15 JLCPCB | 0.147
 | R21 | 1.2K | 0805 |  | Select by System | 0805W8F1201T5E | UNI-ROYAL(Uniroyal Elec) | 0805 | -55℃~+155℃ 1.2kΩ 125mW 150V Thick Film Resistor ±1% ±100ppm/℃ 0805 Chip Resistor - Surface Mount ROHS | Chip Resistor - Surface Mount |  | C17379 | https://jlcpcb.com/partdetail/18067-0805W8F1201T5E/C17379 | Basic | 20 | 20 JLCPCB | 0.182
 | R24,R26,R31,R35,R7,R9 | 100K | 0402 |  | Select by System | 0402WGF1003TCE | UNI-ROYAL(Uniroyal Elec) | 0402 | -55℃~+155℃ 100kΩ 50V 62.5mW Thick Film Resistor ±1% ±100ppm/℃ 0402 Chip Resistor - Surface Mount ROHS | Chip Resistor - Surface Mount |  | C25741 | https://jlcpcb.com/partdetail/26484-0402WGF1003TCE/C25741 | Basic | 40 | 40 JLCPCB | 0.144
 | R25 | 200K | 0402 |  | Select by System | 0402WGF2003TCE | UNI-ROYAL(Uniroyal Elec) | 0402 | -55℃~+155℃ 200kΩ 50V 62.5mW Thick Film Resistor ±1% ±100ppm/℃ 0402 Chip Resistor - Surface Mount ROHS | Chip Resistor - Surface Mount |  | C25764 | https://jlcpcb.com/partdetail/26507-0402WGF2003TCE/C25764 | Basic | 20 | 20 JLCPCB | 0.036
 | R28 | 1M | 0402 |  | Select by System | FRC0402F1004TS | FOJAN | 0402 | -55℃~+155℃ 1MΩ 50V 62.5mW Thick Film Resistor ±1% ±100ppm/℃ 0402 Chip Resistor - Surface Mount ROHS | Chip Resistor - Surface Mount |  | C2909328 | https://jlcpcb.com/partdetail/FOJAN-FRC0402F1004TS/C2909328 | Extended | 20 | 20 JLCPCB | 0.042
 | R29 | 178K | 0402 |  | Select by System | FRC0402F1783TS | FOJAN | 0402 | -55℃~+155℃ 178kΩ 50V 62.5mW Thick Film Resistor ±1% ±100ppm/℃ 0402 Chip Resistor - Surface Mount ROHS | Chip Resistor - Surface Mount |  | C3013156 | https://jlcpcb.com/partdetail/FOJAN-FRC0402F1783TS/C3013156 | Extended | 20 | 20 JLCPCB | 0.04
 | R30 | 100R | 0402 |  | Select by System | FRC0402J101 TS | FOJAN | 0402 | -55℃~+155℃ 100Ω 50V 62.5mW Thick Film Resistor ±100ppm/℃ ±5% 0402 Chip Resistor - Surface Mount ROHS | Chip Resistor - Surface Mount |  | C2906884 | https://jlcpcb.com/partdetail/FOJAN-FRC0402J101TS/C2906884 | Extended | 20 | 20 JLCPCB | 0.044
 | R32,R33,R34 | 4.7K | 0402 |  | Select by System | FRC0402J472 TS | FOJAN | 0402 | -55℃~+155℃ 4.7kΩ 50V 62.5mW Thick Film Resistor ±100ppm/℃ ±5% 0402 Chip Resistor - Surface Mount ROHS | Chip Resistor - Surface Mount |  | C2906941 | https://jlcpcb.com/partdetail/FOJAN-FRC0402J472TS/C2906941 | Extended | 25 | 25 JLCPCB | 0.0475
 | SAO0,SAO1 | HC-PM254-8.5H-2X3PS | C22373944_HDR-SMD_6P-P2_54-V-F-R2-C3-LS7_1 |  | Select by System | HC-PM254-8.5H-2x3PS | Hong Cheng | SMD,P=2.54mm | -40℃~+105℃ 2 2.54mm 2.54mm 2x3P 3A 6P 8.5mm Brass Gold Square Hole Surface Mount,Vertical Top SMD,P=2.54mm Female Headers ROHS | Female Headers |  | C22373944 | https://jlcpcb.com/partdetail/HongCheng-HC_PM254_8_5H2x3PS/C22373944 | Extended | 10 | 10 JLCPCB | 1.636
 | SW1,SW6 | TS-1187A-B-A-B | SW_Push_1P1T_XKB_TS-1187A |  | Select by System | TS-1187A-B-A-B | XKB Connection | SMD-4P,5.1x5.1mm | -30℃~+85℃ 1.5mm 1.6N 100,000 cycles 12V 5.1mm 5.1mm 50mA Gold No Round Button SPST Surface Mount,Vertical Without Bracket SMD-4P,5.1x5.1mm Tactile Switches ROHS | Tactile Switches |  | C318884 | https://jlcpcb.com/partdetail/XKBConnection-TS_1187A_B_AB/C318884 | Basic | 15 | 15 JLCPCB | 0.306
 | SW2,SW3 | K2-1112SW-A4SW-04 | K2-1112SW-A4SW-04 |  | Select by System | K2-1112SW-A4SW-04 | Korean Hroparts Elec | 弯插,7x3.5mm | -25℃~+85℃ 100,000 cycles 12V 2.5N 3.5mm 3.95mm 50mA 7mm Rectangular Button Right Angle SPST 弯插,7x3.5mm Tactile Switches ROHS | Tactile Switches |  | C223811 | https://jlcpcb.com/partdetail/223956-K2_1112SW_A4SW04/C223811 | Extended | 14 | 14 JLCPCB | 0.9688
SW4,SW5 |  | XDTD-6650 | SW_Push_1P1T_NO_E-Switch_TL3301NxxxxxG |  | Select by System | XDTD-6643-L01 | Lian Xin Technology | SMD | -45℃~+80℃ 12V 2.6N 4.3mm 50,000 cycles 50mA 6mm 6mm Black Gull Wing No Round Button SPST Surface Mount,Vertical Without Bracket SMD Tactile Switches ROHS | Tactile Switches |  | C7498208 | https://jlcpcb.com/partdetail/Lian_XinTechnology-XDTD_6643L01/C7498208 | Extended | 10 | 10 JLCPCB | 0.316
 | SW7 | SW_SPDT | SPDTSMDslideswitch |  | Select by System | SSSS811101 | ALPSALPINE | SMD | -40℃~+85℃ 10,000 cycles 300mA 4.1mm 5V Rectangular Columnar SMD(SMT) Tab SPDT Surface Mount, Right Angle SMD Slide Switches ROHS | Slide Switches |  | C109335 | https://jlcpcb.com/partdetail/ALPSALPINE-SSSS811101/C109335 | Extended | 7 | 7 JLCPCB | 1.0318
U1 |  | RP2040 | QFN-56-1EP_7x7mm_P0.4mm_EP3.2x3.2mm |  | Select by System | RP2040 | Raspberry Pi | LQFN-56(7x7) | 12bit 133MHz 30 LQFN-56(7x7) Microcontrollers (MCU/MPU/SOC) ROHS | Microcontrollers (MCU/MPU/SOC) |  | C2040 | https://jlcpcb.com/partdetail/RaspberryPi-RP2040/C2040 | Extended | 5 | 5 JLCPCB | 4.9255
 | U2 | 74HC139 | SOIC-16_3.9x9.9mm_P1.27mm |  | Select by System | 74HC139D,653 | Nexperia | SOIC-16 | -40℃~+125℃ 11ns@6.0V,50pF 160uA 2/4 2V~6V 74HC Decoder Single Supply SOIC-16 Signal Switches, Multiplexers, Decoders ROHS | Signal Switches, Multiplexers, Decoders |  | C5603 | https://jlcpcb.com/partdetail/Nexperia-74HC139D653/C5603 | Extended | 5 | 5 JLCPCB | 2.6685
 | U3 | W25Q128JVSIQ | SOIC-8_5.3x5.3mm_P1.27mm |  | Select by System | W25Q128JVSIQ | Winbond Elec | SOIC-8-208mil | -40℃~+85℃ 100,000 cycles 120ms@(32KB) 128Mbit 133MHz 1uA 2.7V~3.6V 20 Years 3ms Power-on reset、Hardware write protection、Software write protection、Write enable latch、Absolute write protection SPI SOIC-8-208mil NOR FLASH ROHS | NOR FLASH |  | C97521 | https://jlcpcb.com/partdetail/WinbondElec-W25Q128JVSIQ/C97521 | Basic | 5 | 5 JLCPCB | 12.632
 | U4 | CC1101RGPR | QFN-20-1EP_L4.0-W4.0-P0.5-EP2.4 |  | Select by System | CC1101RGPR | Texas Instruments | QFN-20-EP(4x4) | -112dBm -40℃~+85℃ 1.8V~3.6V 12dBm 15.7mA 300MHz~348MHz、387MHz~464MHz、779MHz~928MHz 315MHz、433MHz、868MHz、915MHz 34.2mA 500Kbps ISM SPI transceiver QFN-20-EP(4x4) RF Transceiver ICs ROHS | RF Transceiver ICs |  | C29953 | https://jlcpcb.com/partdetail/TexasInstruments-CC1101RGPR/C29953 | Extended | 5 | 5 JLCPCB | 8.0615
 | U5 | TP4056 | ESOP-8_L4.9-W3.9-P1.27-LS6.0-BL-EP |  | Select by System | TP4056 | UMW(Youtai Semiconductor Co., Ltd.) | ESOP-8 | -40℃~+85℃ 1 1A 35uA 4.2V 4V~6.5V Charging IC Lithium Battery Support Support 恒流充电、恒压充电、涓流充电、自动再充电、充电终止、可编程充电电流、软启动、欠压锁定 ESOP-8 Battery Management ROHS | Battery Management |  | C725790 | https://jlcpcb.com/partdetail/772193-TP4056/C725790 | Extended | 5 | 5 JLCPCB | 0.417
 | U6 | TPS63000 | Texas_DRC0010J |  | Select by System | TPS63000DRCR | Texas Instruments | SON-10-EP(3.1x3.1) | -40℃~+85℃@(TA) 1 1.2V~5.5V 1.5MHz 1.8V~5.5V 50uA Adjustable Buck-Boost Buck-Boost Built-in Yes SON-10-EP(3.1x3.1) DC-DC Converters ROHS | DC-DC Converters |  | C24966 | https://jlcpcb.com/partdetail/TexasInstruments-TPS63000DRCR/C24966 | Extended | 5 | 5 JLCPCB | 4.571
 | U7 | LM321 | SOT-23-5 |  | Select by System | LM321H-TR | Gainsil | SOT-23-5 | -18V~-1.5V、1.5V~18V -25℃~+85℃ 1 1MHz 200V/ms 20nA 250uA 3V~36V 5mV 5nA 60mA 7uV/℃ 80dB Built-in compensation SOT-23-5 Operational Amplifier ROHS | Operational Amplifier |  | C2927688 | https://jlcpcb.com/partdetail/Gainsil-LM321HTR/C2927688 | Extended | 7 | 7 JLCPCB | 0.6293
 | X1 | ABM8-272-T3 | Crystal_SMD_Abracon_ABM8AIG-4Pin_3.2x2.5mm |  | Select by System | ABM8-272-T3 | Abracon LLC | SMD3225-4P | -40℃~+85℃ 10pF 12MHz 50Ω Crystal Oscillator ±30ppm ±30ppm SMD3225-4P Crystals ROHS | Crystals |  | C20625731 | https://jlcpcb.com/partdetail/AbraconLLC-ABM8_272T3/C20625731 | Extended | 5 | 5 JLCPCB | 1.4665
 | X2 | 26MHz | Crystal_SMD_3225-4Pin_3.2x2.5mm |  | Select by System | S3226000151040 | JGHC | SMD3225-4P | -40℃~+85℃ 15pF 26MHz 40Ω Crystal Oscillator ±10ppm SMD3225-4P Crystals ROHS | Crystals |  | C479205 | https://jlcpcb.com/partdetail/JGHC-S3226000151040/C479205 | Extended | 9 | 9 JLCPCB | 0.6201

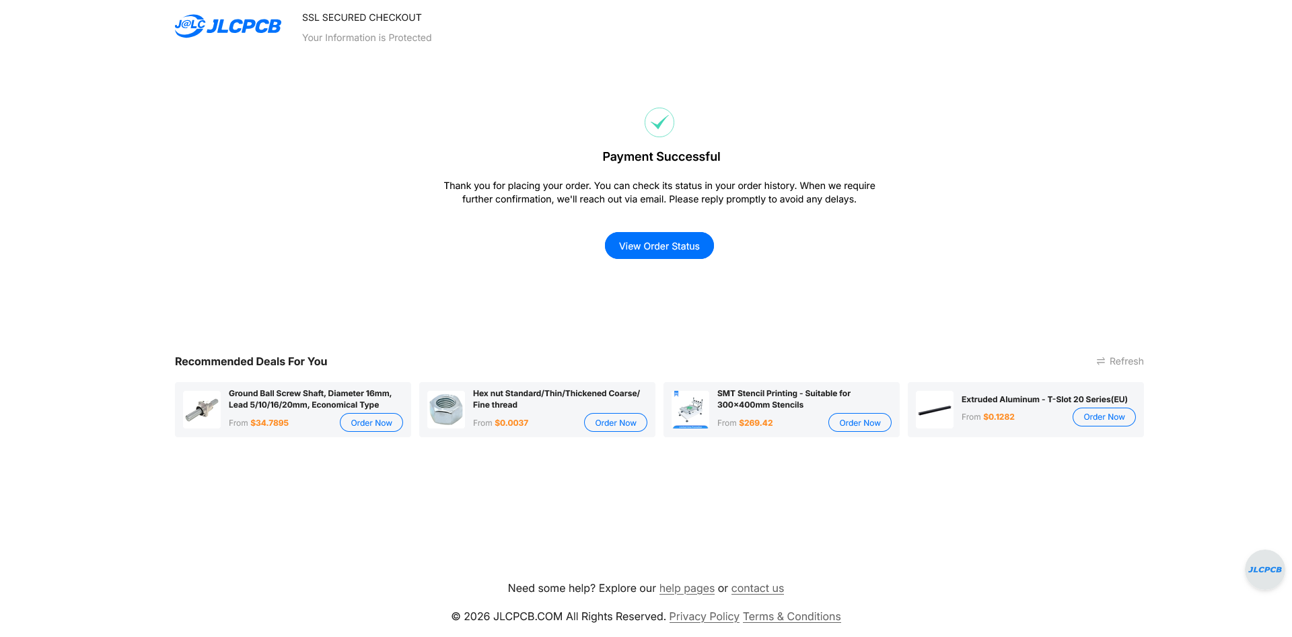
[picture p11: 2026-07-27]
KiCad_src_V1_2/production_SMT026072760780_PCB_V_1_2/Screenshot 2026-07-27 at 09-32-52 JLCPCB Checkout Secure Your Order Payment & Fast Processing.png

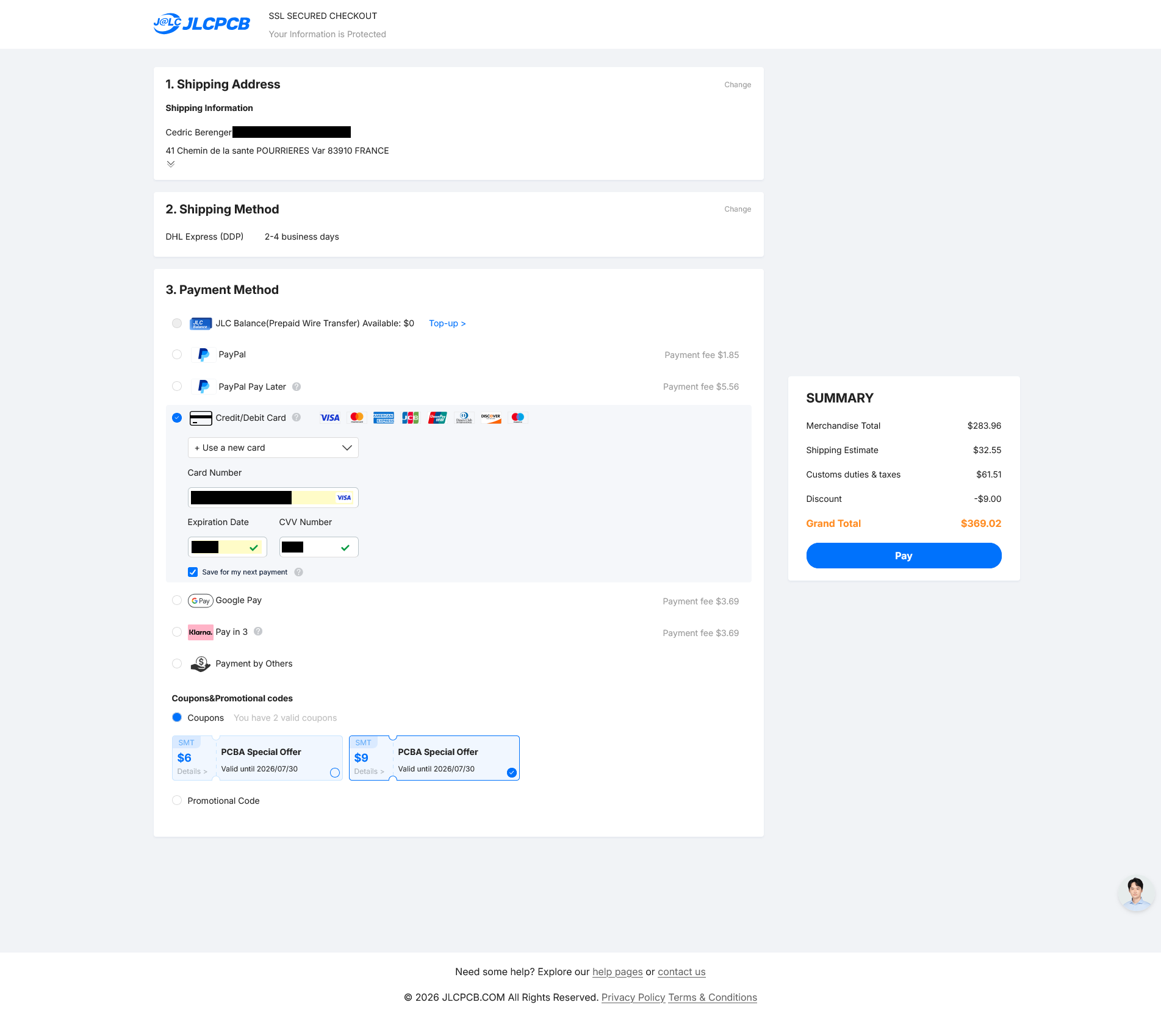
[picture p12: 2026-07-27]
KiCad_src_V1_2/production_SMT026072760780_PCB_V_1_2/Screenshot 2026-07-27 at 09-31-52 JLCPCB Checkout Secure Your Order Payment & Fast Processing.png

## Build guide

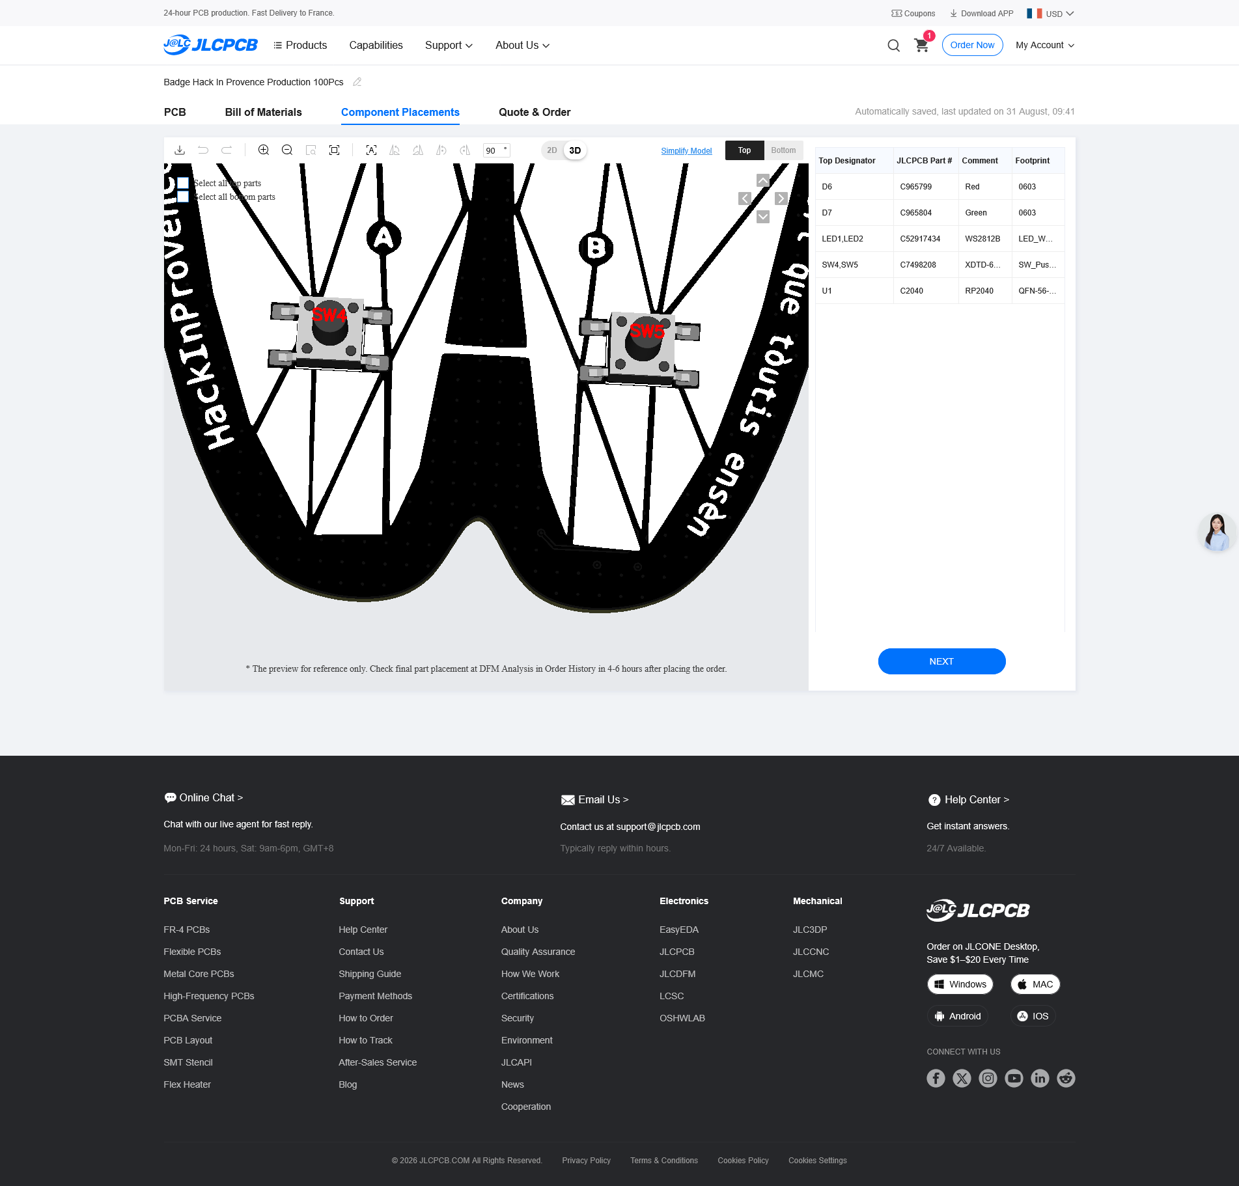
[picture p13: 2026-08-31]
KiCad_src_V1_2/production_preview_reorder_100pcs/res/Assembly_Buttons_Close_View.png

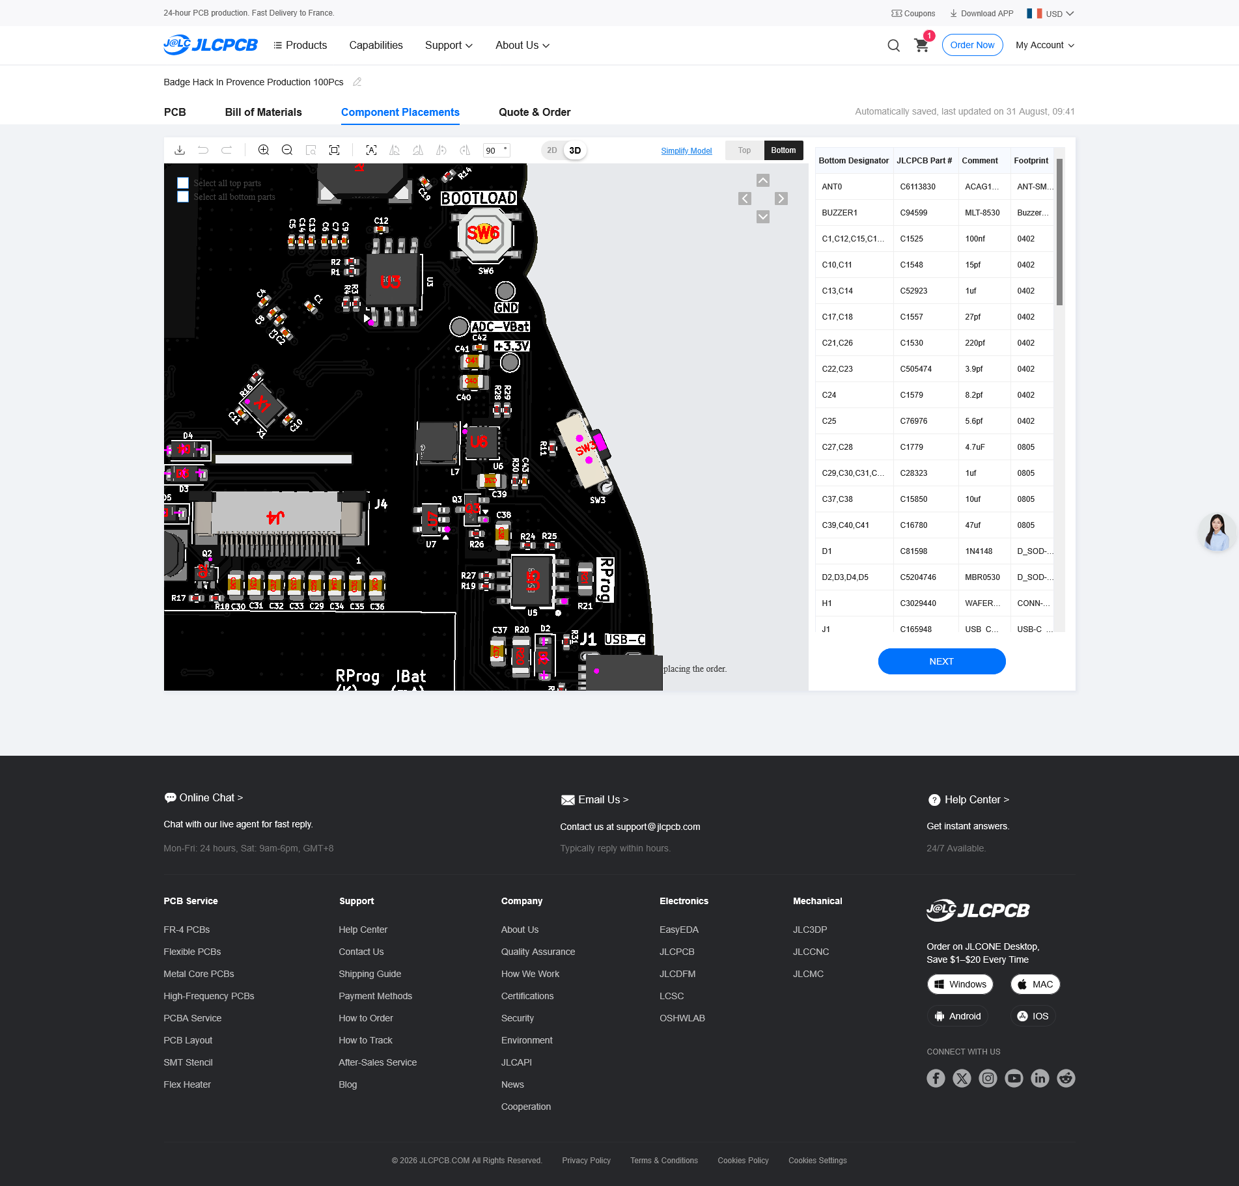
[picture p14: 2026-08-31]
KiCad_src_V1_2/production_preview_reorder_100pcs/res/Assembly_close_view_1.png

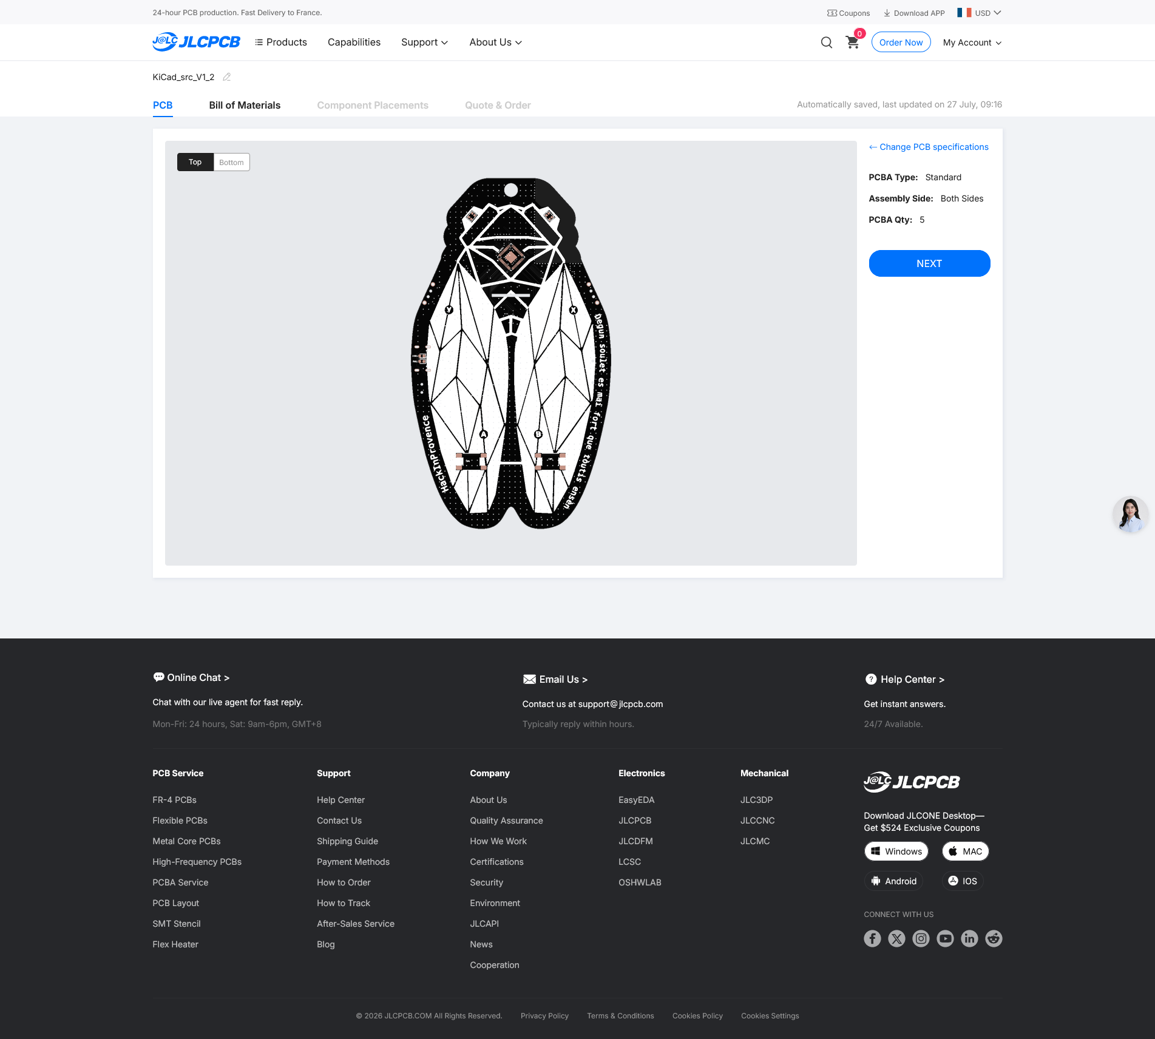
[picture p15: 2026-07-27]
KiCad_src_V1_2/production_SMT026072760780_PCB_V_1_2/Screenshot 2026-07-27 at 09-16-58 PCB Prototype & PCB Fabrication Manufacturer - JLCPCB.png

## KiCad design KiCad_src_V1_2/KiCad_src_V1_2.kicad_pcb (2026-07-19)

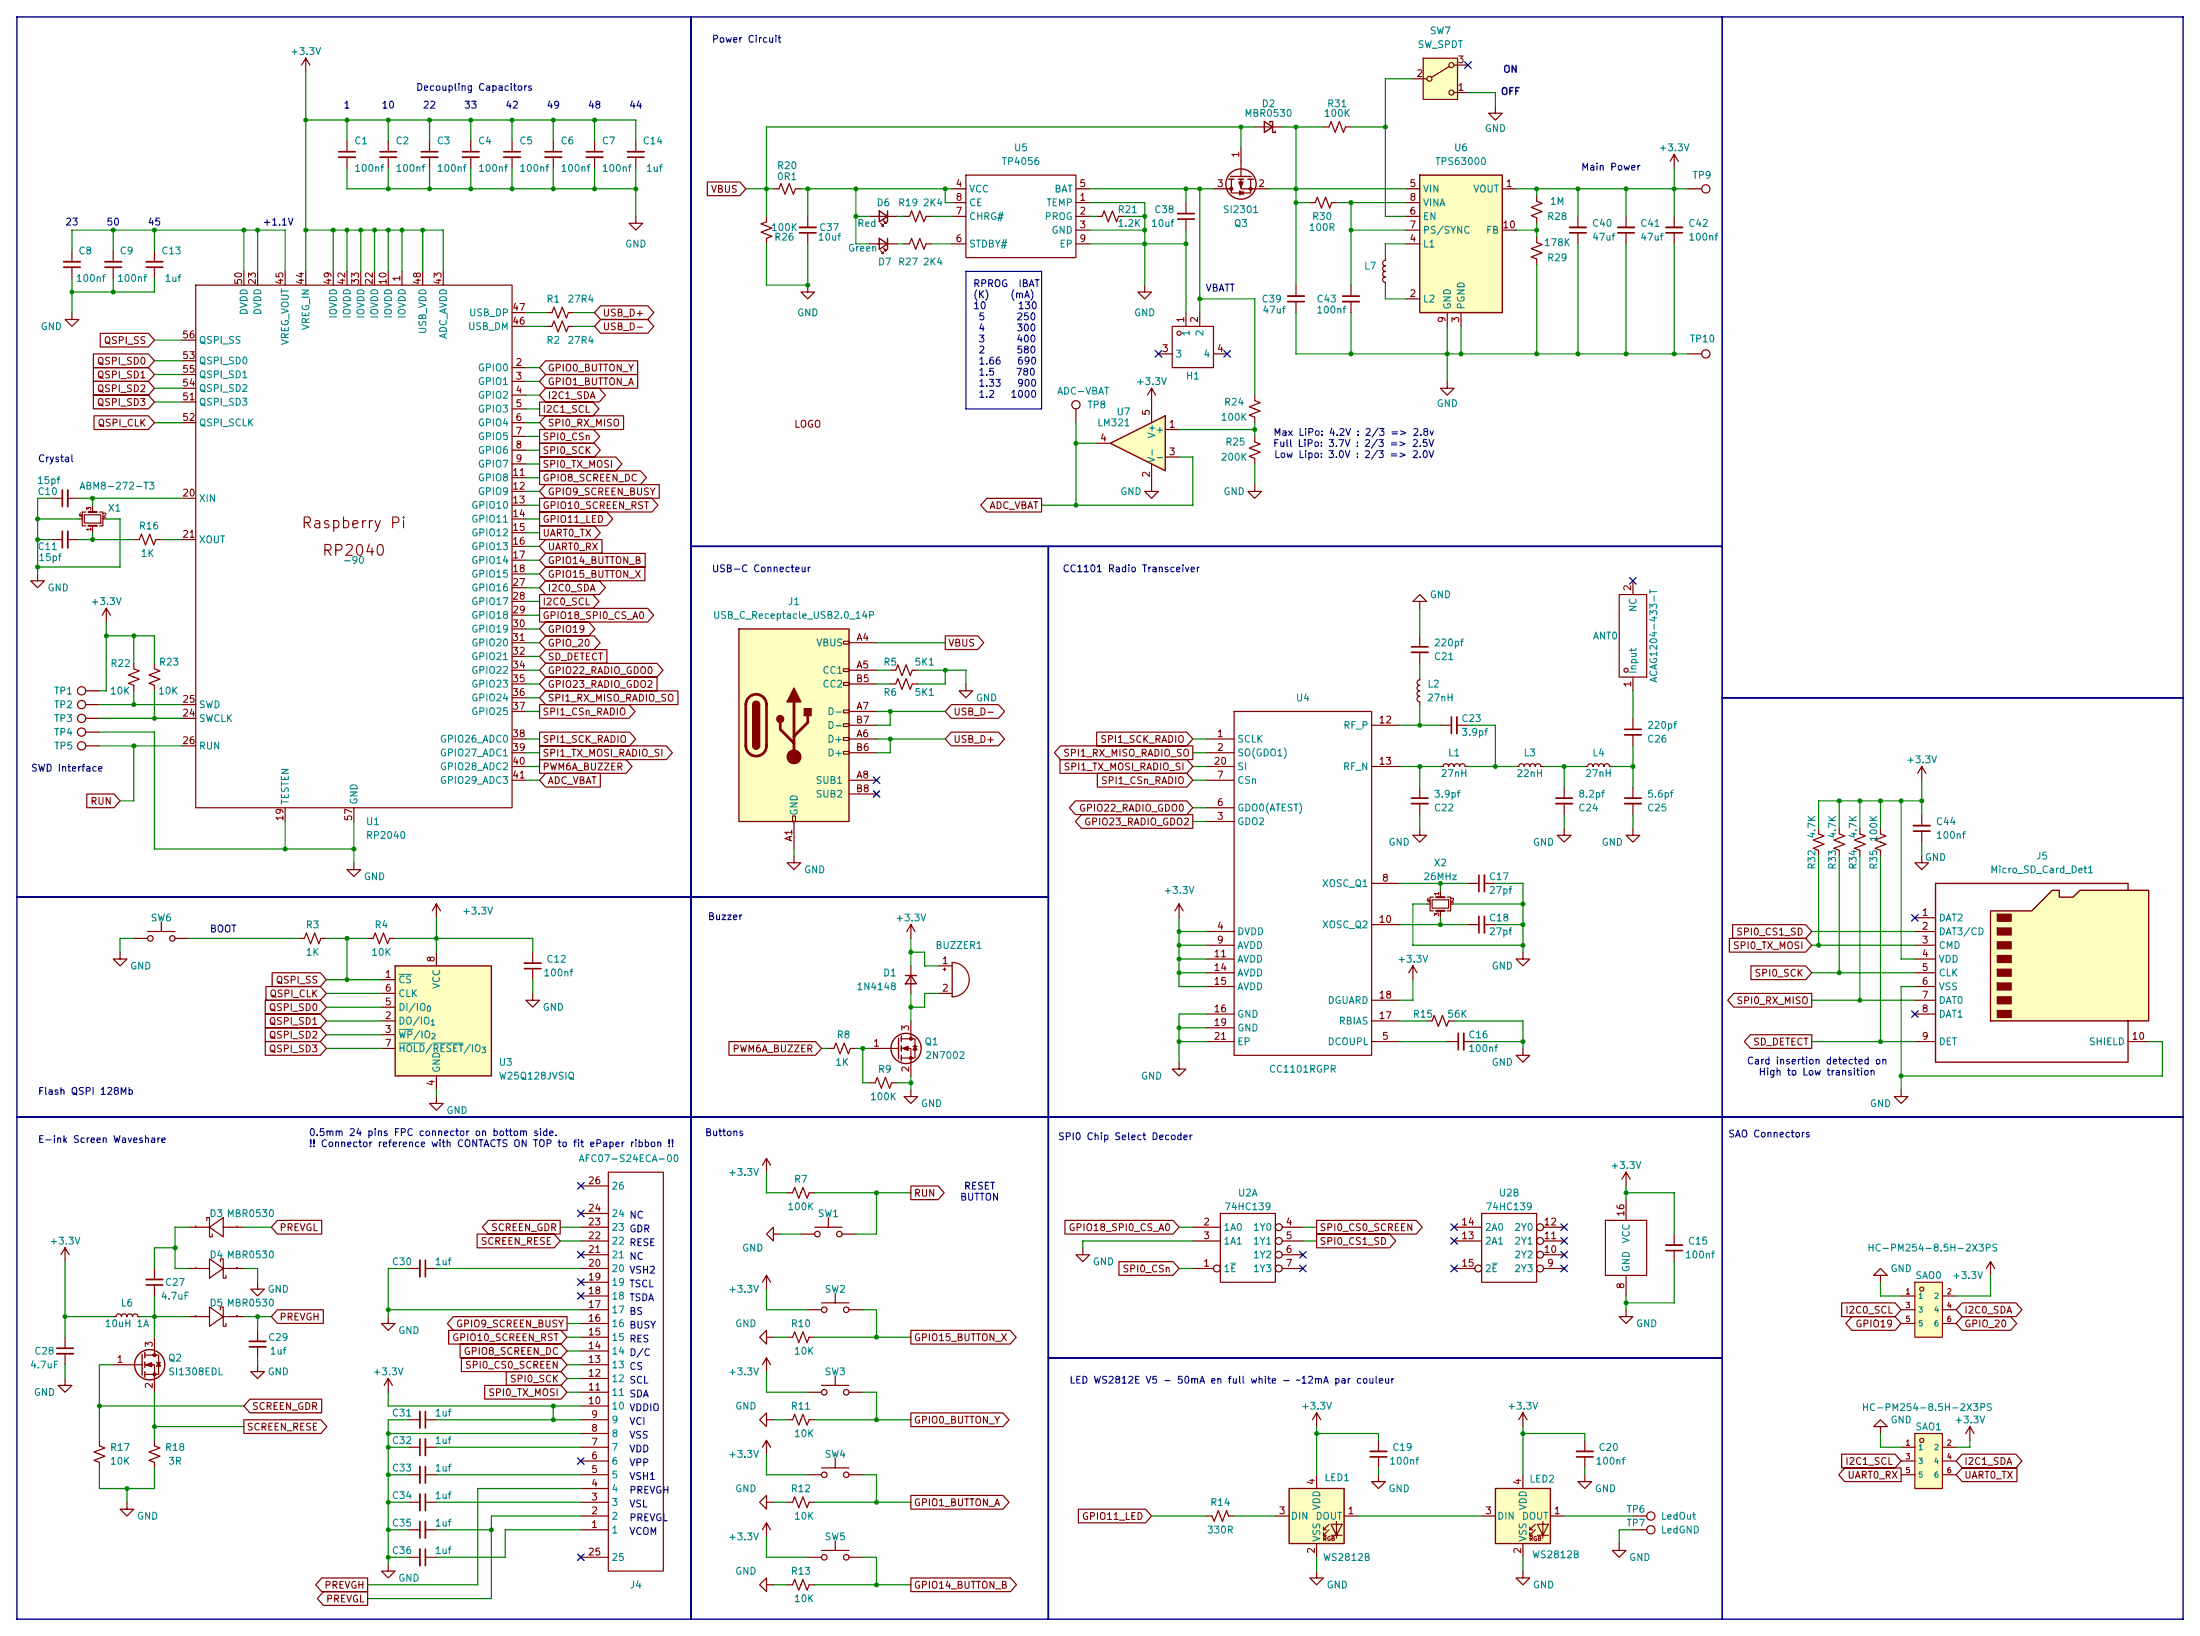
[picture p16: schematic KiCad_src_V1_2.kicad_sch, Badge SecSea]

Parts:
ANT0: ACAG1204-433-T; ANT-SMD_L12.0-W4.0_ACAG1204-915-T; Manufacturer Part ACAG1204-433-T; LCSC Part # C6113830
BUZZER1: MLT-8530; Buzzer MLT-8530; Manufacturer Part MLT-8530; LCSC Part # C94599
C1, C2, C3, C4, C5, C6, C7, C8, C9, C12, C15, C16, C19, C20, C42, C43, C44: 100nf; C_0402_1005Metric; Manufacturer Part CL05B104KO5NNNC; LCSC Part # C1525
C10, C11: 15pf; C_0402_1005Metric; Manufacturer Part 0402CG150J500NT; LCSC Part # C1548
C13, C14: 1uf; C_0402_1005Metric; Manufacturer Part CL05A105KA5NQNC; LCSC Part # C52923
C17, C18: 27pf; C_0402_1005Metric; Manufacturer Part 0402CG270J500NT; LCSC Part # C1557
C21, C26: 220pf; C_0402_1005Metric; Manufacturer Part 0402B221K500NT; LCSC Part # C1530
C22, C23: 3.9pf; C_0402_1005Metric; Manufacturer Part CC0402BRNPO9BN3R9; LCSC Part # C505474
C24: 8.2pf; C_0402_1005Metric; Manufacturer Part 0402CG8R2C500NT; LCSC Part # C1579
C25: 5.6pf; C_0402_1005Metric; Manufacturer Part GRM1555C1H5R6BA01D; LCSC Part # C76976
C27, C28: 4.7uF; C_0805_2012Metric; Manufacturer Part CL21A475KAQNNNE; LCSC Part # C1779
C29, C30, C31, C32, C33, C34, C35, C36: 1uf; C_0805_2012Metric; Manufacturer Part CL21B105KBFNNNE; LCSC Part # C28323
C37, C38: 10uf; C_0805_2012Metric; Manufacturer Part CL21A106KAYNNNE; LCSC Part # C15850
C39, C40, C41: 47uf; C_0805_2012Metric; Manufacturer Part CL21A476MQYNNNE; LCSC Part # C16780
D1: 1N4148; D_SOD-123; Manufacturer Part 1N4148W; LCSC Part # C81598
D2, D3, D4, D5: MBR0530; D_SOD-123; Manufacturer Part MBR0530; LCSC Part # C5204746
D6: Red; LED_0603_1608Metric; Manufacturer Part XL-1608SURC-06; LCSC Part # C965799
D7: Green; LED_0603_1608Metric; Manufacturer Part XL-1608UGC-04; LCSC Part # C965804
G1: LOGO; silkscreen_cigale
H1: WAFER-PH2.0-2PWB; CONN-SMD_2P-P2.00_XUNPU_WAFER-PH2.0-2PWB; Manufacturer Part WAFER-PH2.0-2PWB; LCSC Part # C3029440
J1: USB_C_Receptacle_USB2.0_14P; USB-C_C165948; Manufacturer Part TYPE-C-31-M-12; LCSC Part # C165948
J4: AFC07-S24ECA-00; FPC_24; Manufacturer Part AFC07-S24ECA-00; LCSC Part # C262643
J5: Micro_SD_Card_Det1; MicroSD TF-115-BCP9; Manufacturer Part XUNPU TF-115-BCP9; LCSC Part # C720505
L1, L2, L4: 27nH; L_0402_1005Metric; Manufacturer Part LQG15HS27NJ02D; LCSC Part # C12669
L3: 22nH; L_0402_1005Metric; Manufacturer Part SDCL1005C22NJTDF; LCSC Part # C15178
L6: 10uH 1A; L_Ferrocore_DLG-0403; Manufacturer Part CY43-10UH; LCSC Part # C2929419
L7: 2.2µH; L_APV_ANR4012; Manufacturer Part NR4018S2R2MT; LCSC Part # C28642347
LED1, LED2: WS2812B; LED_WS2812B-2020_PLCC4_2.0x2.0mm; Manufacturer Part WS2812B-2020; LCSC Part # C965555
Q1: 2N7002; SOT-23; Manufacturer Part 2N7002; LCSC Part # C8545
Q2: SI1308EDL; SOT-323_SC-70; Manufacturer Part SI1308EDL; LCSC Part # C7603347
Q3: SI2301; SOT-23; Manufacturer Part SI2301; LCSC Part # C2891731
R1, R2: 27R4; R_0402_1005Metric; Manufacturer Part RC-02W27R4FT; LCSC Part # C321420
R3, R8, R16: 1K; R_0402_1005Metric; Manufacturer Part 0402WGF1001TCE; LCSC Part # C11702
R4, R10, R11, R12, R13, R17, R22, R23: 10K; R_0402_1005Metric; Manufacturer Part 0402WGF1002TCE; LCSC Part # C25744
R5, R6: 5K1; R_0402_1005Metric; Manufacturer Part 0402WGF5101TCE; LCSC Part # C25905
R7, R9, R24, R26, R31, R35: 100K; R_0402_1005Metric; Manufacturer Part 0402WGF1003TCE; LCSC Part # C25741
R14: 330R; R_0402_1005Metric; Manufacturer Part 0402WGF3300TCE; LCSC Part # C25104
R15: 56K; R_0402_1005Metric; Manufacturer Part 0402WGF5602TCE; LCSC Part # C25796
R18: 3R; R_0402_1005Metric; Manufacturer Part FRC0402F3R00TS; LCSC Part # C2933093
R19, R27: 2K4; R_0402_1005Metric; Manufacturer Part 0402WGF2401TCE; LCSC Part # C25882
R20: 0R1; R_1206_3216Metric; Manufacturer Part 1206W4F100LT5E; LCSC Part # C25334
R21: 1.2K; R_0805_2012Metric_Pad1.20x1.40mm_HandSolder; Manufacturer Part 0805W8F1201T5E; LCSC Part # C17379
R25: 200K; R_0402_1005Metric; Manufacturer Part 0402WGF2003TCE; LCSC Part # C25764
R28: 1M; R_0402_1005Metric; Manufacturer Part FRC0402F1004TS; LCSC Part # C2909328
R29: 178K; R_0402_1005Metric; Manufacturer Part FRC0402F1783TS; LCSC Part # C3013156
R30: 100R; R_0402_1005Metric; Manufacturer Part FRC0402J101TS; LCSC Part # C2906884
R32, R33, R34: 4.7K; R_0402_1005Metric; Manufacturer Part FRC0402J472 TS; LCSC Part # C2906941
SAO0, SAO1: HC-PM254-8.5H-2X3PS; C22373944_HDR-SMD_6P-P2_54-V-F-R2-C3-LS7_1; LCSC C22373944
SW1, SW6: TS-1187A-B-A-B; SW_Push_1P1T_XKB_TS-1187A; Manufacturer Part TS-1187A-B-A-B; LCSC Part # C318884
SW2, SW3: K2-1112SW-A4SW-04; Manufacturer Part K2-1112SW-A4SW-04; LCSC Part # C223811
SW4, SW5: XDTD-6650; SW_Push_1P1T_NO_E-Switch_TL3301NxxxxxG; Manufacturer Part XDTD-6643-L01; LCSC Part # C7498208
SW7: SW_SPDT; SPDT SMD slide switch; Manufacturer Part SSSS811101; LCSC Part # C109335
TP1, TP2, TP3, TP4, TP5: TestPoint; TestPoint_Pad_D1.5mm
TP6: LedOut; TestPoint_Pad_D1.5mm
TP7: LedGND; TestPoint_Pad_D1.5mm
TP8, TP9, TP10: ADC-VBAT; TestPoint_Pad_D1.5mm
U1: RP2040; QFN-56-1EP_7x7mm_P0.4mm_EP3.2x3.2mm; Manufacturer Part RP2040; LCSC Part # C2040
U2: 74HC139; SOIC-16_3.9x9.9mm_P1.27mm; Manufacturer Part 74HC139D,653; LCSC Part # C5603
U3: W25Q128JVSIQ; SOIC-8_5.3x5.3mm_P1.27mm; Manufacturer Part W25Q128JVSIQ; LCSC Part # C97521
U4: CC1101RGPR; QFN-20-1EP_L4.0-W4.0-P0.5-EP2.4; Manufacturer Part CC1101RGPR; LCSC Part # C29953
U5: TP4056; ESOP-8_L4.9-W3.9-P1.27-LS6.0-BL-EP; Manufacturer Part TP4056; LCSC Part # C725790
U6: TPS63000; Texas_DRC0010J; Manufacturer Part TPS63000DRCR; LCSC Part # C24966
U7: LM321; SOT-23-5; Manufacturer Part LM321H-TR; LCSC Part # C2927688
X1: ABM8-272-T3; Crystal_SMD_Abracon_ABM8AIG-4Pin_3.2x2.5mm; Manufacturer Part ABM8-272-T3; LCSC Part # C20625731
X2: 26MHz; Crystal_SMD_3225-4Pin_3.2x2.5mm; Manufacturer Part S3226000151040; LCSC Part # C479205

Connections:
+3.3V: BUZZER1.1 (+), C1.1, C2.1, C3.1, C4.1, C5.1, C6.1, C7.1, C12.2, C14.2, C15.2, C19.2, C20.2, C28.1, C31.1, C40.2, C41.2, C42.2, C44.2, D1.1 (K), J4.9, J4.10, J5.4 (VDD), L6.1, LED1.4 (VDD), LED2.4 (VDD), R4.2, R7.1, R22.2, R23.2, R28.1, R32.2, R33.2, R34.2, R35.2, SAO0.2, SAO1.2, SW2.1, SW3.2, SW4.2, SW5.2, TP1.1 (1_1), TP9.1 (1_1), U1.1 (IOVDD), U1.10 (IOVDD), U1.22 (IOVDD), U1.33 (IOVDD), U1.42 (IOVDD), U1.43 (ADC_AVDD), U1.44 (VREG_IN), U1.48 (USB_VDD), U1.49 (IOVDD), U2.16 (VCC), U3.8 (VCC), U4.4 (DVDD), U4.9 (AVDD), U4.11 (AVDD), U4.14 (AVDD), U4.15 (AVDD), U4.18 (DGUARD), U6.1 (VOUT), U7.5 (V+)
ADC_VBAT: TP8.1 (1_1), U1.41 (GPIO29_ADC3), U7.3 (-), U7.4
GND: C1.2, C2.2, C3.2, C4.2, C5.2, C6.2, C7.2, C8.1, C9.1, C10.1, C11.1, C12.1, C13.1, C14.1, C15.1, C16.2, C17.2, C18.2, C19.1, C20.1, C21.1, C22.2, C24.2, C25.2, C28.2, C29.1, C30.2, C31.2, C32.1, C33.2, C34.2, C35.1, C36.2, C37.1, C38.1, C39.1, C40.1, C41.1, C42.1, C43.2, C44.1, D4.1 (K), H1.1, J1.A1 (GND), J1.B1 (GND), J4.8, J4.17, J5.6 (VSS), J5.10 (SHIELD), LED1.2 (VSS), LED2.2 (VSS), Q1.2 (S), R5.1, R6.2, R9.2, R10.1, R11.1, R12.1, R13.1, R15.2, R17.1, R18.1, R21.1, R25.1, R26.2, R29.2, SAO0.1, SAO1.1, SW1.1, SW6.1, SW7.1 (C), TP4.1 (1_1), TP7.1 (1_1), TP10.1 (1_1), U1.19 (TESTEN), U1.57 (GND), U2.3 (1A1), U2.8 (GND), U3.4 (GND), U4.16 (GND), U4.19 (GND), U4.21 (EP), U5.1 (TEMP), U5.3 (GND), U5.9 (EP), U6.3 (PGND), U6.9 (GND), U6.11 (PGND), U7.2 (V-), X1.2, X1.4, X2.2, X2.4
GPIO0_BUTTON_Y: R11.2, SW3.1, U1.2 (GPIO0)
GPIO1_BUTTON_A: R12.2, SW4.1, U1.3 (GPIO1)
GPIO8_SCREEN_DC: J4.14, U1.11 (GPIO8)
GPIO9_SCREEN_BUSY: J4.16, U1.12 (GPIO9)
GPIO10_SCREEN_RST: J4.15, U1.13 (GPIO10)
GPIO11_LED: R14.1, U1.14 (GPIO11)
GPIO14_BUTTON_B: R13.2, SW5.1, U1.17 (GPIO14)
GPIO15_BUTTON_X: R10.2, SW2.2, U1.18 (GPIO15)
GPIO18_SPI0_CS_A0: U1.29 (GPIO18), U2.2 (1A0)
GPIO19: SAO0.5, U1.30 (GPIO19)
GPIO22_RADIO_GDO0: U1.34 (GPIO22), U4.6 (GDO0(ATEST))
GPIO23_RADIO_GDO2: U1.35 (GPIO23), U4.3 (GDO2)
GPIO_20: SAO0.6, U1.31 (GPIO20)
I2C0_SCL: SAO0.3, U1.28 (GPIO17)
I2C0_SDA: SAO0.4, U1.27 (GPIO16)
I2C1_SCL: SAO1.3, U1.5 (GPIO3)
I2C1_SDA: SAO1.4, U1.4 (GPIO2)
unnamed: ANT0.1 (Input_1), C26.1
unnamed: BUZZER1.2 (-), D1.2 (A), Q1.3 (D)
unnamed: C11.2, R16.1, X1.1
unnamed: C21.2, L2.2
unnamed: C23.2, L1.2, L3.1
unnamed: C24.1, L3.2, L4.1
unnamed: C25.1, C26.2, L4.2
unnamed: C30.1, J4.20
unnamed: C32.2, J4.7
unnamed: C33.1, J4.5
unnamed: C34.1, J4.3
unnamed: C36.1, J4.1
unnamed: C39.2, D2.1 (K), Q3.2 (S), R30.2, R31.1, U6.5 (VIN)
unnamed: C27.2, D3.1 (K), D4.2 (A)
unnamed: C27.1, D5.2 (A), L6.2, Q2.3 (D)
unnamed: C37.2, D6.2 (A), D7.2 (A), R20.1, U5.4 (VCC), U5.8 (CE)
unnamed: D6.1 (K), R19.2
unnamed: D7.1 (K), R27.2
unnamed: J1.A5 (CC1), R5.2
unnamed: J1.B5 (CC2), R6.1
unnamed: LED1.3 (DIN), R14.2
unnamed: LED1.1 (DOUT), LED2.3 (DIN)
unnamed: LED2.1 (DOUT), TP6.1 (1_1)
unnamed: Q1.1 (G), R8.2, R9.1
unnamed: C38.2, H1.2, Q3.3 (D), R24.2, U5.5 (BAT)
unnamed: R3.2, SW6.2
unnamed: R31.2, SW7.2 (B), U6.6 (EN)
unnamed: R23.1, TP3.1 (1_1), U1.24 (SWCLK)
unnamed: R22.1, TP2.1 (1_1), U1.25 (SWD)
unnamed: R2.1, U1.46 (USB_DM)
unnamed: R1.2, U1.47 (USB_DP)
unnamed: C8.2, C9.2, C13.2, U1.23 (DVDD), U1.45 (VREG_VOUT), U1.50 (DVDD)
unnamed: C10.2, U1.20 (XIN), X1.3
unnamed: R16.2, U1.21 (XOUT)
unnamed: C16.1, U4.5 (DCOUPL)
unnamed: R15.1, U4.17 (RBIAS)
unnamed: C22.1, L1.1, U4.13 (RF_N)
unnamed: C23.1, L2.1, U4.12 (RF_P)
unnamed: C17.1, U4.8 (XOSC_Q1), X2.1
unnamed: C18.1, U4.10 (XOSC_Q2), X2.3
unnamed: R19.1, U5.7 (CHRG#)
unnamed: R21.2, U5.2 (PROG)
unnamed: R27.1, U5.6 (STDBY#)
unnamed: R28.2, R29.1, U6.10 (FB)
unnamed: L7.2, U6.4 (L1)
unnamed: L7.1, U6.2 (L2)
unnamed: C43.1, R30.1, U6.7 (PS/SYNC), U6.8 (VINA)
unnamed: R24.1, R25.2, U7.1 (+)
PREVGH: C29.2, D5.1 (K), J4.4
PREVGL: C35.2, D3.2 (A), J4.2
PWM6A_BUZZER: R8.1, U1.40 (GPIO28_ADC2)
QSPI_CLK: U1.52 (QSPI_SCLK), U3.6 (CLK)
QSPI_SD0: U1.53 (QSPI_SD0), U3.5 (DI/IO_{0})
QSPI_SD1: U1.55 (QSPI_SD1), U3.2 (DO/IO_{1})
QSPI_SD2: U1.54 (QSPI_SD2), U3.3 (~WP/IO_{2})
QSPI_SD3: U1.51 (QSPI_SD3), U3.7 (~HOLD/~RESET/IO_{3})
QSPI_SS: R3.1, R4.1, U1.56 (QSPI_SS), U3.1 (~CS)
RUN: R7.2, SW1.2, TP5.1 (1_1), U1.26 (RUN)
SCREEN_GDR: J4.23, Q2.1 (G), R17.2
SCREEN_RESE: J4.22, Q2.2 (S), R18.2
SD_DETECT: J5.9 (DET), R35.1, U1.32 (GPIO21)
SPI0_CS0_SCREEN: J4.13, U2.4 (1Y0)
SPI0_CS1_SD: J5.2 (DAT3/CD), U2.5 (1Y1)
SPI0_CSn: U1.7 (GPIO5), U2.1 (1~E)
SPI0_RX_MISO: J5.7 (DAT0), R34.1, U1.6 (GPIO4)
SPI0_SCK: J4.12, J5.5 (CLK), R33.1, U1.8 (GPIO6)
SPI0_TX_MOSI: J4.11, J5.3 (CMD), R32.1, U1.9 (GPIO7)
SPI1_CSn_RADIO: U1.37 (GPIO25), U4.7 (CSn)
SPI1_RX_MISO_RADIO_SO: U1.36 (GPIO24), U4.2 (SO(GDO1))
SPI1_SCK_RADIO: U1.38 (GPIO26_ADC0), U4.1 (SCLK)
SPI1_TX_MOSI_RADIO_SI: U1.39 (GPIO27_ADC1), U4.20 (SI)
UART0_RX: SAO1.5, U1.16 (GPIO13)
UART0_TX: SAO1.6, U1.15 (GPIO12)
USB_D+: J1.A6 (D+), J1.B6 (D+), R1.1
USB_D-: J1.A7 (D-), J1.B7 (D-), R2.2
VBUS: D2.2 (A), J1.A4 (VBUS), J1.B4 (VBUS), Q3.1 (G), R20.2, R26.1

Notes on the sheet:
VDD
VDDIO
E-ink Screen Waveshare
Main Power
RPROG IBAT (K) (mA) 10 130 5 250 4 300 3 400 2 580 1.66 690 1.5 780 1.33 900 1.2 1000
SAO Connectors
VSH1
VPP
TSCL
Flash QSPI 128Mb
VCOM
PREVGH
SDA
VSH2
Max LiPo: 4.2V : 2/3 => 2.8v Full LiPo: 3.7V : 2/3 => 2.5V Low Lipo: 3.0V : 2/3 => 2.0V
Buzzer
ON OFF
+1.1V
RES
GDR
Buttons
D/C
CC1101 Radio Transceiver
Card insertion detected on High to Low transition
VCI
BUSY
Crystal
Decoupling Capacitors
PREVGL
SPI0 Chip Select Decoder
LED WS2812E V5 - 50mA en full white - ~12mA par couleur
VSS
VSL
SCL
RESET BUTTON
VBATT
SWD Interface
Power Circuit
RESE
TSDA

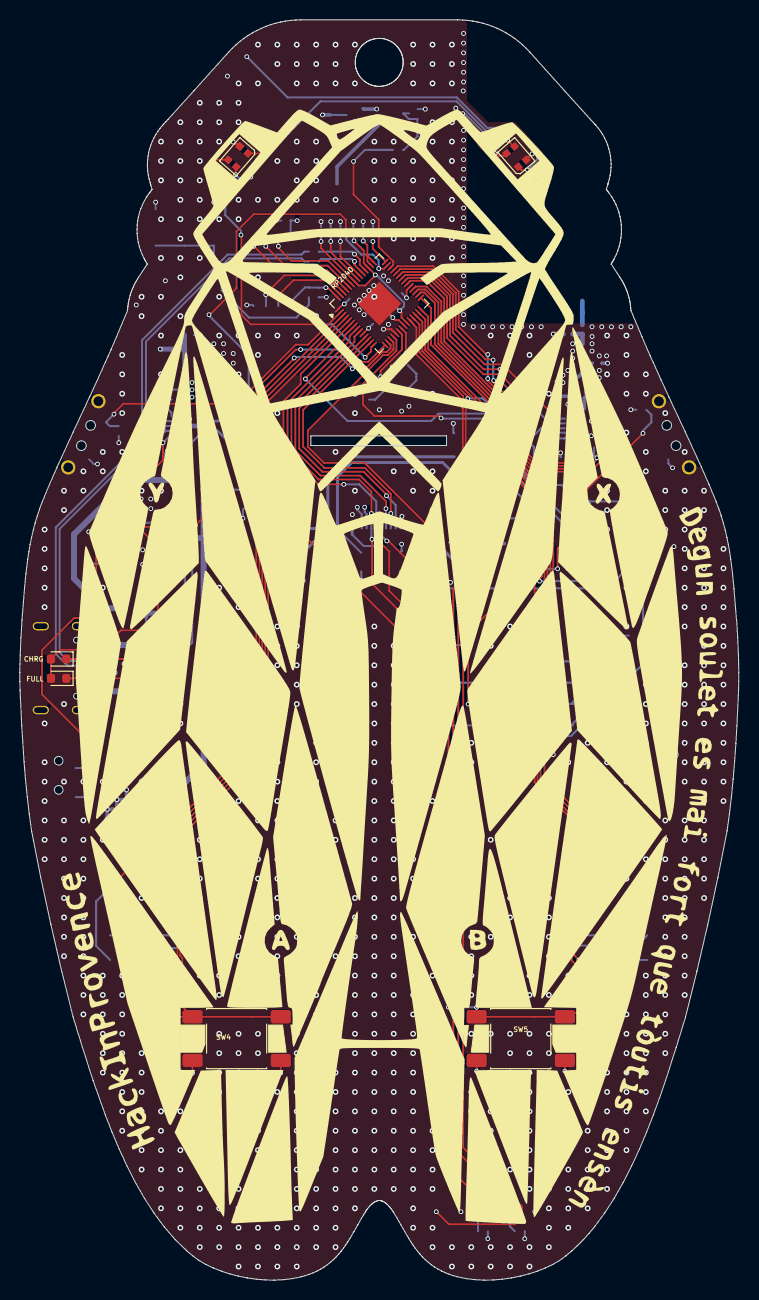
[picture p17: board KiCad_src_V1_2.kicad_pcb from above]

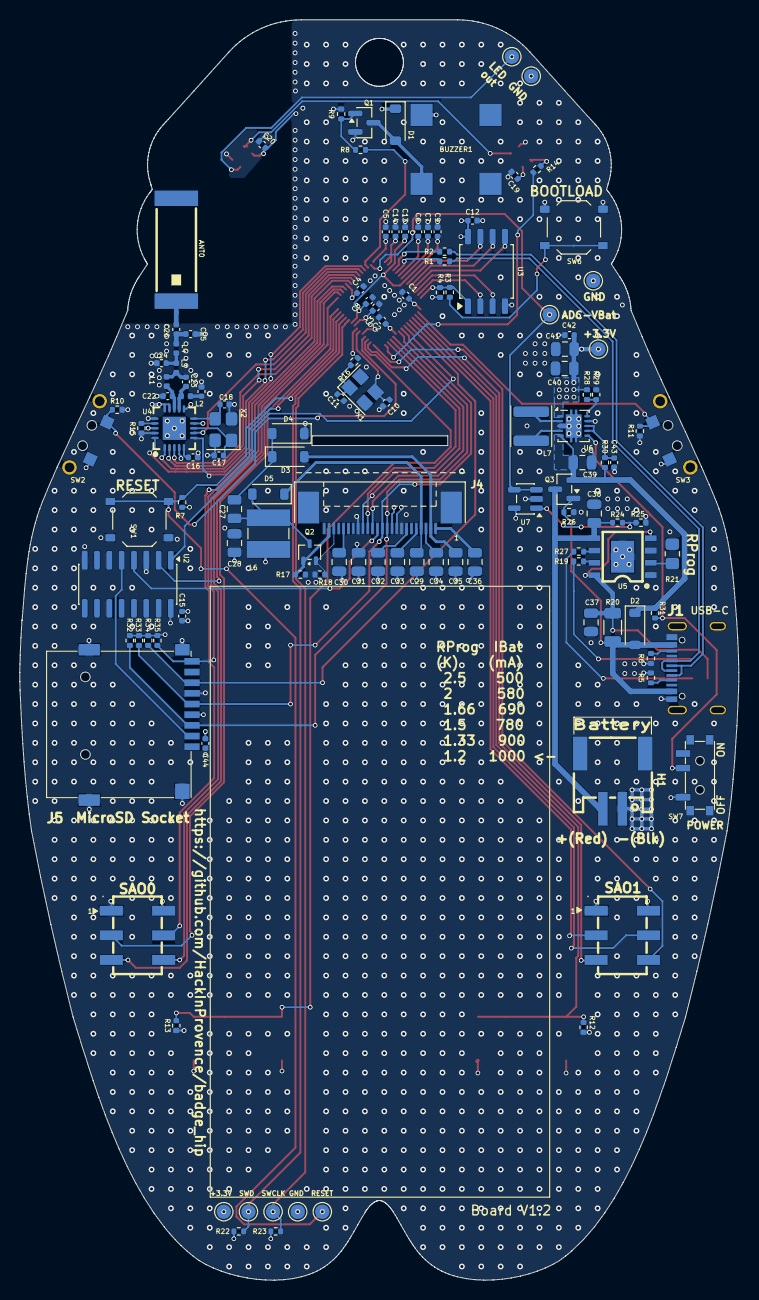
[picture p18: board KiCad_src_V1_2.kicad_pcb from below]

Board: 4 copper layers, 74.1 x 130.0 mm, 132 parts (124 on the bottom side), 96 nets.

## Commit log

2026-01-14 Files import
    [badge_secsea_V1_1.csv, badge_secsea_V1_1.kicad_pcb, badge_secsea_V1_1.kicad_sch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]
2026-01-14 Add files via upload
    file up to date
    [badge_secsea_V1_1.csv]
2026-06-29 Consumption fix: Op amp now connected to +3.3V instead of VBat (Schematic + PCB)
    [badge_secsea_V1_1.kicad_pcb, badge_secsea_V1_1.kicad_sch]
2026-06-29 Working on new antenna keepout zone and position.
    [badge_secsea_V1_1.kicad_pcb]
2026-06-29 SAO connector added (with 3D). WIP on the antenna.
    [badge_secsea_V1_1.kicad_pcb, badge_secsea_V1_1.kicad_sch]
2026-06-29 WIP routing
    [badge_secsea_V1_1.kicad_pcb, badge_secsea_V1_1.kicad_sch]
2026-06-29 WIP Routing....
    [badge_secsea_V1_1.kicad_pcb, badge_secsea_V1_1.kicad_sch]
2026-07-13 fix: complete PCB routing with clean DRC
    All tracks are routed. DRC passes with no errors. Remaining warnings are related to silkscreen graphics and footprint libraries, likely due to outdated footprints following KiCad updates.
    [badge_secsea_V1_1.kicad_pcb]
2026-07-13 fix: update footprints to clear most DRC library warnings
    Updated footprints to resolve the majority of DRC warnings. Remaining warnings: silkscreen issues and missing "Partek" footprint library are still unresolved.
    [badge_secsea_V1_1.kicad_pcb]
2026-07-14 pcb: move some tracks and reduce occupied space using diagonal segments
    [badge_secsea_V1_1.kicad_pcb]
2026-07-14 Removing old backups and production files
    [badge_secsea_V1_1.csv, bom.csv, designators.csv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]
2026-07-18 Review with Miaou
    [badge_secsea_V1_1.kicad_pcb, badge_secsea_V1_1.kicad_sch]
2026-07-19 pcb: SAO connector fixed, LED wires on the bottom plane instead of top.
    [badge_secsea_V1_1.kicad_pcb]
2026-07-19 Schematic backup (before via stitching)
    [badge_secsea_V1_1.kicad_pcb, badge_secsea_V1_1.kicad_sch]
2026-07-19 Project Renamed to V1_2
    [KiCad_src_V1_2.kicad_pcb, KiCad_src_V1_2.kicad_sch, badge_secsea_V1_1.kicad_pcb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]
2026-07-19 Add production preview documentation and associated files for JLCPCB order
    [KiCad_src_V1_2.kicad_pcb, bom-JLCPCB Assembly Order.xls]
2026-07-20 Library for inverted F antenna added (need more room on PCB). Capacitor components changed to C0G
    [KiCad_src_V1_2.kicad_sch]
2026-07-27 JLCPCB: In Production
    [bom-JLCPCB Assembly Order.xls, bom.csv, designators.csv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]
2026-08-31 100pcs assembly.
